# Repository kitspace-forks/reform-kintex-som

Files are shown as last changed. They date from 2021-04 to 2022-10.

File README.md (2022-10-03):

# MNT Reform Kintex-7 SoM (MNT RKX7)

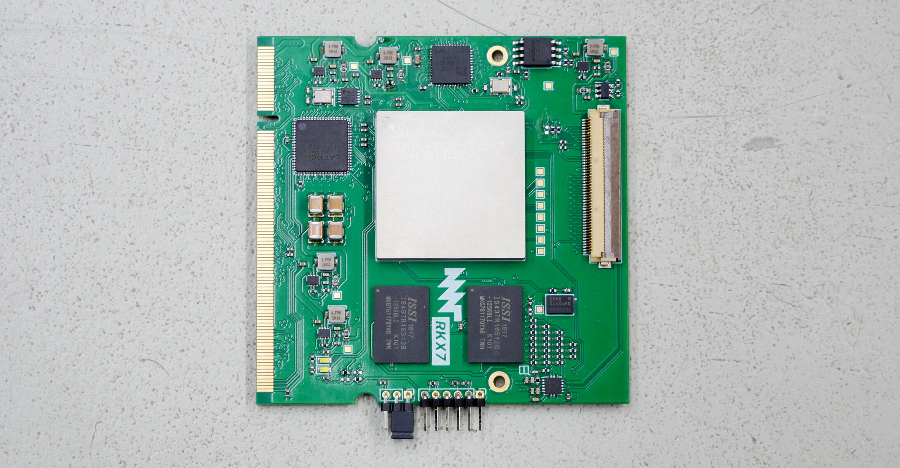
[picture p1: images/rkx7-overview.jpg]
MNT Reform Kintex-7 SoM (MNT RKX7) D-2


This is the open hardware system-on-module featuring the Xilinx/AMD Kintex-7 FPGA (XC7K160T or XC7K325T) and 2GB DDR3 RAM. It can be used as an alternative to the main processor module in the [MNT Reform open hardware laptop](https://www.crowdsupply.com/mnt/reform) or in any other custom device. The idea is to test synthesized open cores such as [CORE-V CVA6](https://github.com/openhwgroup/cva6) (RISC-V), [LiteX](https://github.com/enjoy-digital/litex) (multi-architecture), [LibreSOC](https://libre-soc.org/) (OpenPOWER) in a real laptop. True emulation of vintage computer architectures in a laptop form factor is possible as well.

The module was designed by Lukas F. Hartmann (mntmn) of [MNT Research GmbH](https://mntre.com).

## Status

In September 2022 we assembled and brought up the second revision of the module (D-2) which fixes some problems found in the first revision. We were able to run a full RISC-V Linux desktop on the new module, integrated in the MNT Reform laptop shell. We are using the XC7K325T-FFG676 FPGA. For details, see [the MNT Reform Kintex-7 SoM Showcase](https://mntre.com/media/reform_md/2022-09-29-rkx7-showcase.html).

Changes from D-1:

- The power sequencing IC was missing pullups on the outputs.
- The DDR3 memory routing was completely redone for a less congested layout and avoiding crosstalk. This fixed some address bus errors of the first version.
- The TC358778XBG MIPI encoder was removed. Instead, 24-bit parallel RGB, clocks and extra GPIOs are routed out to a new 50 pin FPC header. This makes the module more flexibly usable.
- We designed a new adapter PCB featuring the Analogix ANX9807 RGB to eDP chip. We are able to successfully drive MNT Reform's eDP Full HD display.
- The TUSB1310ZAY USB3/2 PHY was removed as it is EOL, expensive and there was is no available XHCI host implementation that could drive it. Instead, USB1/2 pads are now driven directly by the FPGA. This works well with the SpinalHDL OHCI host controller which is supported by LiteX.
- 8 FPGA additional pads were broken out to an array of square test points.
- The JTAG header pitch was increased to 2mm for easier access.

The design was created using [KiCAD, a free and open source EDA program](https://www.kicad.org/).

## Specs

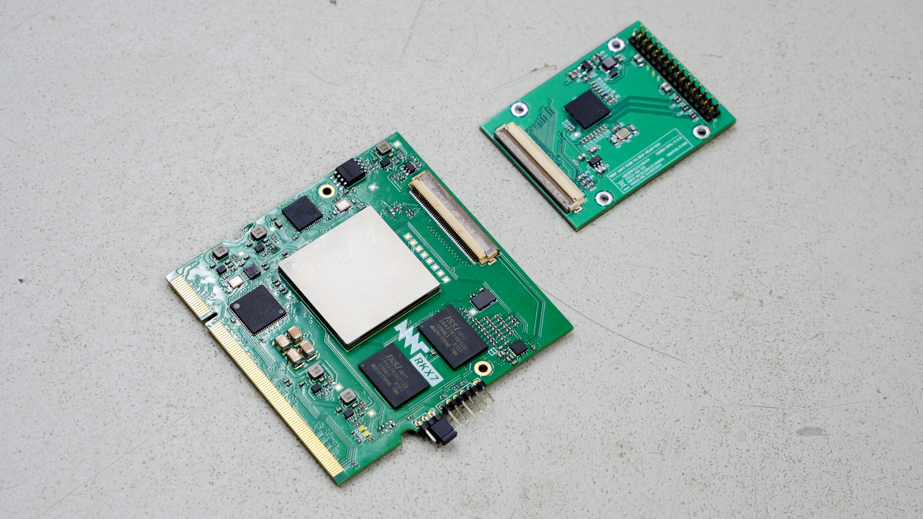
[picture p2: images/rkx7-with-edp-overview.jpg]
MNT Reform Kintex-7 SoM (MNT RKX7) D-2 with eDP module


- FPGA: [Xilinx Kintex-7](https://www.xilinx.com/products/silicon-devices/fpga/kintex-7.html) XC7K160T-FFG676 or pin-compatible family members. We are using XC7K325T-FFG676 in our tests.
- Memory: 2GB DDR3 (2x Micron IS43TR16512B-125KBLI in 32-bit topology)
- 100 MHz main clock oscillator
- HDMI 1.4 (Full HD) implemented via Sii9022 encoder
- 1 GBit Ethernet via KSZ9031RNX PHY
- 2x PCIe lanes connected to GTX transceivers
- 1x USB3 connected to GTX transceiver
- 3x UART, 2x I2C, 1x SAI, 1x PWM backlight ports connected to FPGA fabric
- 128 MBit configuration flash (Winbond W25Q128JVSIM)
- JTAG header
- 6 synchronous buck converters powered by single 5V input
- Size: 68x67.5mm, 200 pin SO-DIMM card edge (mates with TE 1717254-1 or TE 1473005-1)
- Schematics: [PDF](reform-kintex-schematics.pdf)

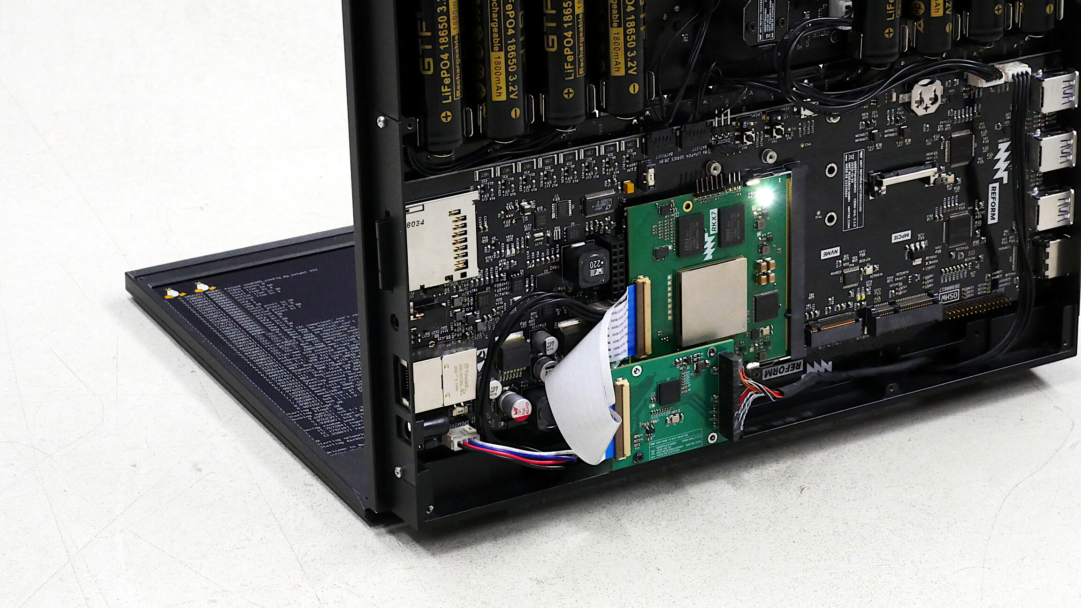
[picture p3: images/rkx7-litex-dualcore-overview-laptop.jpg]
MNT Reform Kintex-7 SoM (MNT RKX7) integrated in MNT Reform laptop


## Copyright

All hardware design work in this repository is © 2021-2022 [MNT Research GmbH](https://mntre.com), Berlin, Germany.

## License

All hardware sources are licensed under the [CERN Open Hardware Licence Version 2 - Strongly Reciprocal](https://ohwr.org/project/cernohl/wikis/uploads/002d0b7d5066e6b3829168730237bddb/cern_ohl_s_v2.txt).

## Funding

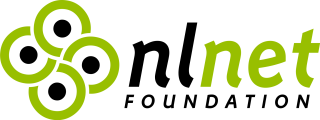
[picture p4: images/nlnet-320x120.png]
NLNet logo


This project [is made possible through funding by NLNet](https://nlnet.nl/project/MNT-Reform/). Thanks!

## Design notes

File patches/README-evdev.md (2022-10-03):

# Evdev Caveat

When demoing Xorg on RKX7 with Linux-on-LiteX-VexRiscV, I encountered the problem that Xorg did not react to any keyboard or mouse input events sent be evdev/libinput. This was due to a disagreement of the timestamps in `struct input_event` in the Linux kernel vs the UAPI used by buildroot: the kernel was producing 32 bit sec/usec values while the userland was expecting 64 bit. I'm not sure how this could happen because buildroot builds both the kernel and the userland.

In any case, my workaround was to patch `struct input_event` in the kernel, in `include/uapi/input.h`:

```c
struct input_event {
	int64_t __sec;
	int64_t __usec;
#define input_event_sec  __sec
#define input_event_usec __usec
	__u16 type;
	__u16 code;
	__s32 value;
};
```

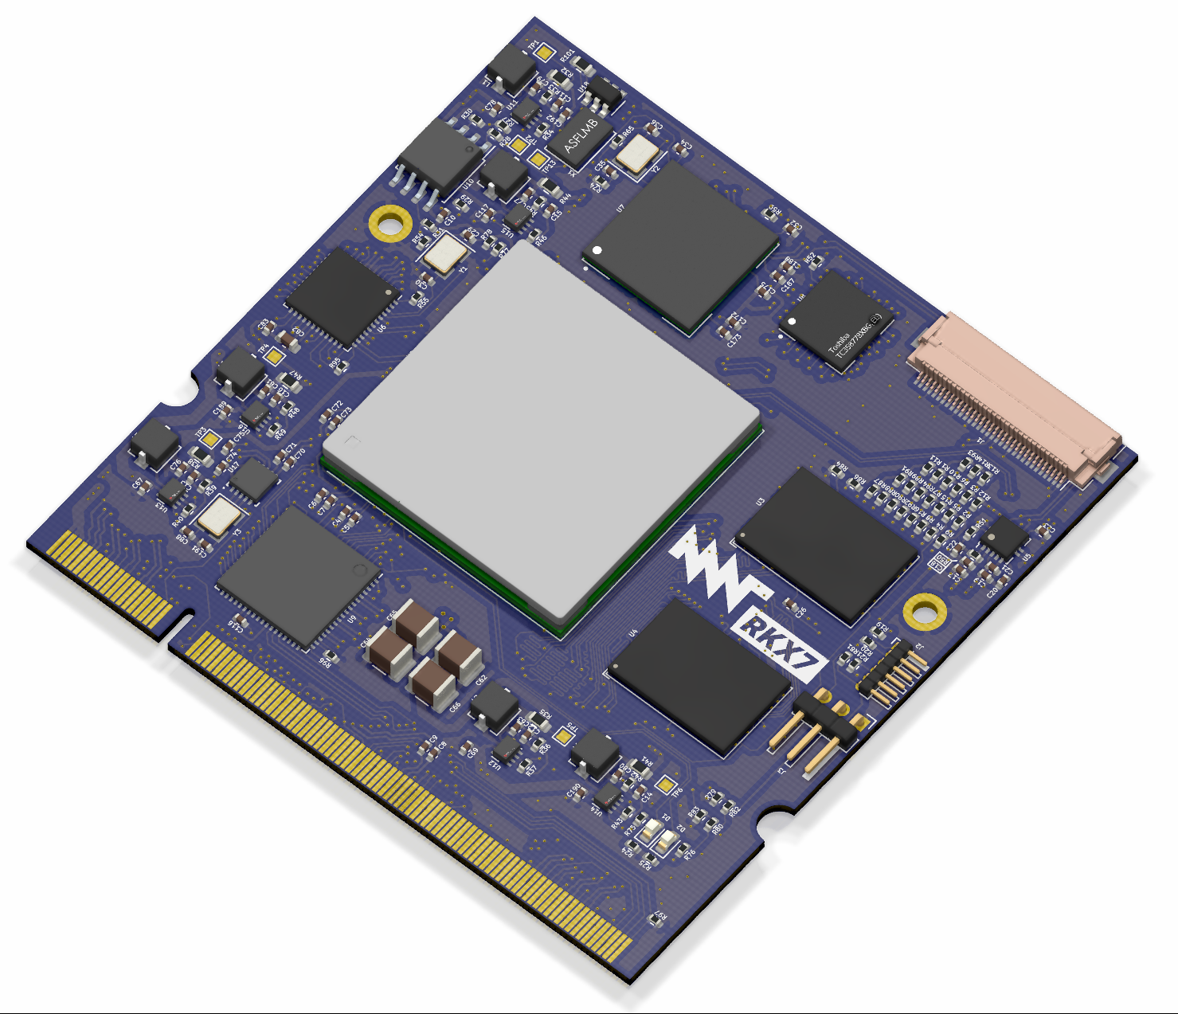
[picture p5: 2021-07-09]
images/mnt-rkx7-3d.png

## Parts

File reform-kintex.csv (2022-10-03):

Source: | /home/mntmn/code/reform-kintex/reform-kintex-pcb/reform-kintex.kicad_sch
Date: | 2022-09-13T12:17:49 CEST
Tool: | Eeschema 6.0.7+dfsg-1+b1
Generator: | /usr/share/kicad/plugins/bom_csv_grouped_by_value_with_fp.py
Component Count: | 297
Ref | Qnty | Value | Cmp name | Footprint | Description | Vendor
C1, C2, C3, C4, C5, C6, C7, C8, C9, C10, C15, C23, C28, C31, C32, C70, C71, C72, C73, C74, C83, C84, C85, C86, C87, C90, C91, C92, C95, C96, C99, C100, C102, C110, C111, C112, C113, C114, C115, C116, C118, C119, C120, C130, C131, C132, C133, C134, C135, C136, C137, C138, C139, C140, C141, C142, C143, C144, C145, C146, C147, C148, C149, C150, C151, C152, C153, C154, C155, C156, C157, C158, C159, C160, C161, C162, C163, C164, C165, C192, | 80 | 0.1uF | C_Small | Capacitor_SMD:C_0402_1005Metric | Unpolarized capacitor, small symbol
C11, C12, C13, C14, C16, | 5 | 120pF | C_Small | Capacitor_SMD:C_0402_1005Metric | Unpolarized capacitor, small symbol
C17, C18, C19, C20, C21, C63, C76, C79, C80, C81, C101, | 11 | 10uF | C_Small | Capacitor_SMD:C_0402_1005Metric | Unpolarized capacitor, small symbol
C22, | 1 | 1nF | C_Small | Capacitor_SMD:C_0402_1005Metric | Unpolarized capacitor, small symbol
C24, C25, C26, C27, C103, | 5 | 10nF | C_Small | Capacitor_SMD:C_0402_1005Metric | Unpolarized capacitor, small symbol
C29, C30, C88, C191, | 4 | 22pF | C_Small | Capacitor_SMD:C_0402_1005Metric | Unpolarized capacitor, small symbol
C37, C38, C39, C40, C41, C42, C60, C61, C68, | 9 | 100uF | C_Small | Capacitor_SMD:C_1206_3216Metric | Unpolarized capacitor, small symbol
C43, C44, C45, C46, C47, C48, C49, C50, C51, C56, C57, C58, C59, C67, C69, C75, C78, C104, C105, C106, C107, C108, C109, C189, C190, | 25 | 4.7uF | C_Small | Capacitor_SMD:C_0402_1005Metric | Unpolarized capacitor, small symbol
C52, C53, C54, C55, | 4 | 47uF | C_Small | Capacitor_SMD:C_1206_3216Metric | Unpolarized capacitor, small symbol
C62, C64, C65, C66, | 4 | 220uF | C_Small | Capacitor_SMD:C_1210_3225Metric | Unpolarized capacitor, small symbol
C82, C89, C93, C94, C97, C98, | 6 | 10uF | C_Small | Capacitor_SMD:C_0603_1608Metric | Unpolarized capacitor, small symbol
D1, D2, | 2 | LED_Small | LED_Small | LED_SMD:LED_0603_1608Metric | Light emitting diode, small symbol
FB1, FB2, FB3, | 3 | Ferrite_Bead_Small | FerriteBead_Small | Inductor_SMD:L_0603_1608Metric | Ferrite bead, small symbol
GFX1, | 1 | MountingHole | MountingHole | footprints:mnt-rkx7 | Mounting Hole without connection
GFX2, | 1 | MountingHole | MountingHole | footprints:mnt-rkx7-badge-d02 | Mounting Hole without connection
H1, H2, | 2 | MountingHole_Pad | MountingHole_Pad | MountingHole:MountingHole_2.2mm_M2_DIN965_Pad | Mounting Hole with connection
J1, | 1 | Conn_01x50 | Conn_01x50 | Connector_FFC-FPC:Hirose_FH12-50S-0.5SH_1x50-1MP_P0.50mm_Horizontal | Generic connector, single row, 01x50, script generated (kicad-library-utils/symbol-generators/connector/)
J2, | 1 | JTAG_01x06 | Conn_01x06 | Connector_PinHeader_2.00mm:PinHeader_1x06_P2.00mm_Vertical | Generic connector, single row, 01x06, script generated (kicad-library-utils/schlib/autogen/connector/)
J3, | 1 | Conn_01x03_Male | Conn_01x03_Male | Connector_PinHeader_2.00mm:PinHeader_1x03_P2.00mm_Vertical | Generic connector, single row, 01x03, script generated (kicad-library-utils/schlib/autogen/connector/)
L1, L2, L3, L4, L6, | 5 | IHLP1212AEERR47M11 | L_Small | Inductor_SMD:L_Vishay_IHLP-1212 | Inductor, small symbol
R1, R2, R3, R4, R5, R6, R7, R8, R9, R10, R11, R12, R13, R14, R15, R16, R87, R88, R89, R90, R91, R92, R93, R94, | 24 | 40.2 | R_Small | Resistor_SMD:R_0402_1005Metric | Resistor, small symbol
R17, R18, R86, R99, R100, | 5 | 80.6 | R_Small | Resistor_SMD:R_0402_1005Metric | Resistor, small symbol
R19, R20, R21, R77, R98, | 5 | 100 | R_Small | Resistor_SMD:R_0402_1005Metric | Resistor, small symbol
R22, R23, R26, R30, R31, R71, R75, R95, R102, R103, R104, R105, R106, R107, R108, R109, | 16 | 4.7k | R_Small | Resistor_SMD:R_0402_1005Metric | Resistor, small symbol
R24, R25, | 2 | 200 | R_Small | Resistor_SMD:R_0402_1005Metric | Resistor, small symbol
R27, | 1 | 2.2k | R_Small | Resistor_SMD:R_0402_1005Metric | Resistor, small symbol
R28, R29, R79, R80, R81, R110, | 6 | 0 | R_Small | Resistor_SMD:R_0402_1005Metric | Resistor, small symbol
R32, R35, R38, R41, R47, R101, | 6 | 0 | R_Small | Resistor_SMD:R_0603_1608Metric | Resistor, small symbol
R33, | 1 | 453k | R_Small | Resistor_SMD:R_0402_1005Metric | Resistor, small symbol
R34, R36, R40, R43, R48, R49, R52, R53, | 8 | 100k 1% | R_Small | Resistor_SMD:R_0402_1005Metric | Resistor, small symbol
R37, R42, | 2 | 150k | R_Small | Resistor_SMD:R_0402_1005Metric | Resistor, small symbol
R39, | 1 | 200k | R_Small | Resistor_SMD:R_0402_1005Metric | Resistor, small symbol
R44, R45, | 2 | 20 | R_Small | Resistor_SMD:R_0402_1005Metric | Resistor, small symbol
R46, | 1 | 1.5k | R_Small | Resistor_SMD:R_0402_1005Metric | Resistor, small symbol
R50, R51, R97, | 3 | 10k 1% | R_Small | Resistor_SMD:R_0402_1005Metric | Resistor, small symbol
R54, | 1 | 1.8M | R_Small | Resistor_SMD:R_0402_1005Metric | Resistor, small symbol
R55, | 1 | 12.1k | R_Small | Resistor_SMD:R_0402_1005Metric | Resistor, small symbol
R76, | 1 | 330 | R_Small | Resistor_SMD:R_0402_1005Metric | Resistor, small symbol
R78, R82, R83, | 3 | DNP | R_Small | Resistor_SMD:R_0402_1005Metric | Resistor, small symbol
R84, R85, | 2 | 240 1% | R_Small | Resistor_SMD:R_0402_1005Metric | Resistor, small symbol
R96, | 1 | 5.1k | R_Small | Resistor_SMD:R_0402_1005Metric | Resistor, small symbol
TP1, TP2, TP3, TP4, TP5, TP6, TP7, TP8, TP9, TP10, TP11, TP12, TP13, TP14, TP15, TP16, | 16 | TestPoint | TestPoint | TestPoint:TestPoint_Pad_1.0x1.0mm | test point
U1, | 1 | MNT Reform 2.0 SoM Socket | reform2-som-connector-reform2-som | footprints:ddr2-sodimm200
U2, | 1 | XC7K160T-FFG676 | XC7K160T-FFG676 | Package_BGA:Xilinx_FFG676 | Kintex 7 T 160 XC7K160T-FFG676
U3, U4, | 2 | IS43TR16512B-125KBLI | gkl_mem_MT41K64M16TW-107_J-TR-OrangeCrab-cache | Package_BGA:BGA-96_9.0x13.0mm_Layout2x3x16_P0.8mm
U5, | 1 | TPS51200DRC | TPS51200DRC | Package_SON:VSON-10-1EP_3x3mm_P0.5mm_EP1.65x2.4mm | Sink and Source DDR Termination Regulator, VSON-10
U6, | 1 | KSZ9031RNX | KSZ9031RNXCA | Package_DFN_QFN:QFN-48-1EP_7x7mm_P0.5mm_EP5.15x5.15mm | 10/100/1000Mbps Ethernet Transciever with RGMII Interface, QFN-48
U9, | 1 | SiI9022A | SiI9022A-zz9000 | Package_DFN_QFN:QFN-72-1EP_10x10mm_P0.5mm_EP6x6mm
U10, | 1 | W25Q128JVS | W25Q128JVS | Package_SO:SOIC-8_5.23x5.23mm_P1.27mm | 128Mb Serial Flash Memory, Standard/Dual/Quad SPI, SOIC-8
U11, U12, U13, U14, U16, | 5 | TPS62823DLC | TPS62823DLC | Package_DFN_QFN:Texas_VSON-HR-8_1.5x2mm_P0.5mm | 3A Step-Down Converter with DCS-Control, adjustable output, 2.4-5.5V input voltage, QFN-8
U17, | 1 | Si52112-B5-GM2 | Si52112-B5 | footprints:Silicon_Labs-Si52112-B5-GM2-Level_B
U18, | 1 | LM3880 | LM3880 | Package_TO_SOT_SMD:SOT-23-6 | Simple Power Sequencer, SOT-23-6
X1, | 1 | ASFLMB-100.000MHZ-XY-T | ASE-xxxMHz | footprints:OSCDFN500X320X90-4N | 3.3V CMOS SMD Crystal Clock Oscillator, Abracon
Y1, Y3, | 2 | ABM8G-25.000MHZ-18-D2Y-T | Crystal_GND24_Small | Crystal:Crystal_SMD_3225-4Pin_3.2x2.5mm | Four pin crystal, GND on pins 2 and 4, small symbol

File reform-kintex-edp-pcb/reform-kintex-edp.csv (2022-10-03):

Source: | /home/mntmn/code/reform-kintex/reform-kintex-edp-pcb/reform-kintex-edp.kicad_sch
Date: | 2022-09-16T13:49:18 CEST
Tool: | Eeschema 6.0.7+dfsg-1+b1
Generator: | /usr/share/kicad/plugins/bom_csv_grouped_by_value_with_fp.py
Component Count: | 54
Ref | Qnty | Value | Cmp name | Footprint | Description | Vendor
C1, C17, | 2 | 10uF | C_Small | Capacitor_SMD:C_0603_1608Metric | Unpolarized capacitor, small symbol
C2, C10, | 2 | 4.7uF | C_Small | Capacitor_SMD:C_0603_1608Metric | Unpolarized capacitor, small symbol
C3, C6, | 2 | 18pF | C_Small | Capacitor_SMD:C_0603_1608Metric | Unpolarized capacitor, small symbol
C4, C5, C8, C9, C11, C12, C13, C14, C15, C16, C18, C19, C20, C21, C22, C25, C26, C27, C28, C29, C30, | 21 | 0.1uF | C_Small | Capacitor_SMD:C_0402_1005Metric | Unpolarized capacitor, small symbol
C7, | 1 | 10nF | C_Small | Capacitor_SMD:C_0603_1608Metric | Unpolarized capacitor, small symbol
C23, C24, | 2 | 47uF | C_Small | Capacitor_SMD:C_0805_2012Metric | Unpolarized capacitor, small symbol
D1, | 1 | PMEG1020EA,115 | D_Schottky_Small_Filled | Diode_SMD:D_SOD-323 | Schottky diode, small symbol, filled shape
H1, H2, H3, H4, | 4 | MountingHole_Pad | MountingHole_Pad | MountingHole:MountingHole_2.2mm_M2_DIN965_Pad | Mounting Hole with connection
H5, | 1 | Badge | MountingHole | footprints:mnt-rgb-edp-badge | Mounting Hole without connection
J1, | 1 | Conn_01x50 | Conn_01x50 | Connector_FFC-FPC:Hirose_FH12-50S-0.5SH_1x50-1MP_P0.50mm_Horizontal | Generic connector, single row, 01x50, script generated (kicad-library-utils/symbol-generators/connector/)
J2, | 1 | ~ | Conn_02x15_Odd_Even | Connector_PinHeader_2.00mm:PinHeader_2x15_P2.00mm_Vertical | Generic connector, double row, 02x15, odd/even pin numbering scheme (row 1 odd numbers, row 2 even numbers), script generated (kicad-library-utils/schlib/autogen/connector/)
L1, | 1 | 3.3uH | L_Small | Inductor_SMD:L_1210_3225Metric | Inductor, small symbol
R1, | 1 | 12k 1% | R_Small | Resistor_SMD:R_0603_1608Metric | Resistor, small symbol
R2, R4, R5, R9, R10, | 5 | 0 | R_Small | Resistor_SMD:R_0603_1608Metric | Resistor, small symbol
R3, | 1 | 100k | R_Small | Resistor_SMD:R_0603_1608Metric | Resistor, small symbol
R6, | 1 | 1M | R_Small | Resistor_SMD:R_0603_1608Metric | Resistor, small symbol
R7, R8, | 2 | 15k 1% | R_Small | Resistor_SMD:R_0603_1608Metric | Resistor, small symbol
TP1, | 1 | TestPoint | TestPoint | TestPoint:TestPoint_Pad_D1.0mm | test point
U1, | 1 | LP2985A-25DBVT | LP2985-2.5 | Package_TO_SOT_SMD:SOT-23-5 | 150mA 16V Low-noise Low-dropout Regulator With Shutdown, 2.5V output voltage, SOT-23-5
U2, | 1 | LM2830XQMFE/NOPB | LM2830XQMFE | Package_TO_SOT_SMD:SOT-23-5 | Miniature Step-Down DC-DC Converter for Ultralow Voltage Circuits, 2.5V < Vin < 5.5V, adjustable output voltage, SOT-23-5
U3, | 1 | ANX9807 | ANX9807 | footprints:BGA-ANX-81
Y1, | 1 | 27MHz | Crystal_GND24_Small | Crystal:Crystal_SMD_3225-4Pin_3.2x2.5mm | Four pin crystal, GND on pins 2 and 4, small symbol

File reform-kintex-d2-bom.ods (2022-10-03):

Qty | Reference(s) | Value | DNP | Manufacturer | Manufacturer_No
80 | C1, C2, C3, C4, C5, C6, C7, C8, C9, C10, C15, C23, C28, C31, C32, C70, C71, C72, C73, C74, C83, C84, C85, C86, C87, C90, C91, C92, C95, C96, C99, C100, C102, C110, C111, C112, C113, C114, C115, C116, C118, C119, C120, C130, C131, C132, C133, C134, C135, C136, C137, C138, C139, C140, C141, C142, C143, C144, C145, C146, C147, C148, C149, C150, C151, C152, C153, C154, C155, C156, C157, C158, C159, C160, C161, C162, C163, C164, C165, C192 | 0.1uF |  | Taiyo Yuden | EMF105B7104KVHF
5 | C11, C12, C13, C14, C16 | 120pF |  | Taiyo Yuden | UMK105CG121JV8F
11 | C17, C18, C19, C20, C21, C63, C76, C79, C80, C81, C101 | 10uF |  | Murata | GRM155R60J106ME15D
1 | C22 | 1nF |  | Murata | GRT1555C1H102FA02D
5 | C24, C25, C26, C27, C103 | 10nF |  | Kemet | C0402C103K5RAC7411
4 | C29, C30, C88, C191 | 22pF |  | Kemet | C0402C220J8HACTU
9 | C37, C38, C39, C40, C41, C42, C60, C61, C68 | 100uF |  | Murata | GRM31CR61A107ME05L
25 | C43, C44, C45, C46, C47, C48, C49, C50, C51, C56, C57, C58, C59, C67, C69, C75, C78, C104, C105, C106, C107, C108, C109, C189, C190 | 4.7uF |  | Murata | GRJ155R61A475ME11J
4 | C52, C53, C54, C55 | 47uF |  | Taiyo Yuden | JMK316AC7476ML-T
4 | C62, C64, C65, C66 | 220uF |  | Murata | GRM32ER60J227ME05L
6 | C82, C89, C93, C94, C97, C98 | 10uF |  | Generic | 0603 10V+
2 | D1, D2 | LED_Small |  | Generic | WLED 0603
3 | FB1, FB2, FB3 | Ferrite_Bead_Small |  | Murata | 100ohms @ 100MHz 0603
1 | J1 | Conn_01x50 |  | Hirose | FH12-50S-0.5SH
1 | J2 | JTAG_01x06 |  | Sullins | SMH100-LPSE
1 | J3 | Conn_01x03_Male |  | Harwin | M22-2530346
5 | L1, L2, L3, L4, L6 | IHLP1212AEERR47M11 |  | Vishay Dale | IHLP1212AEERR47M11
24 | R1, R2, R3, R4, R5, R6, R7, R8, R9, R10, R11, R12, R13, R14, R15, R16, R87, R88, R89, R90, R91, R92, R93, R94 | 40.2 |  | Yageo | RT0402FRE0740R2L
5 | R17, R18, R86, R99, R100 | 80.6 |  | Yageo | AF0402FR-0780R6L
5 | R19, R20, R21, R77, R98 | 100 |  | Yageo | RT0402FRE07100RL
16 | R22, R23, R26, R30, R31, R71, R75, R95, R102, R103, R104, R105, R106, R107, R108, R109 | 4.7k |  | Bourns | CR0402-FX-4701GLF
2 | R24, R25 | 200 |  | Yageo | AF0402JR-07200RL
1 | R27 | 2.2k |  | Vishay Dale | CRCW04022K20JNED
6 | R28, R29, R79, R80, R81, R110 | 0 |  | Yageo | AC0402FR-070RL
6 | R32, R35, R38, R41, R47, R101 | 0 |  | Yageo | AC0402FR-070RL
1 | R33 | 453k |  | Yageo | AC0402FR-07453KL
8 | R34, R36, R40, R43, R48, R49, R52, R53 | 100k 1% |  | Vishay Dale | CRCW0402100KFKEDC
2 | R37, R42 | 150k |  | Yageo | RE0402DRE07150KL
1 | R39 | 200k |  | Yageo | RE0402DRE07200KL
2 | R44, R45 | 20 |  | Yageo | AC0402FR-070RL
1 | R46 | 1.5k |  | Yageo | AC0402FR-070RL
3 | R50, R51, R97 | 10k 1% |  | Yageo | RC0402FR-0710KL
1 | R54 | 1.8M |  | Yageo | RC0402FR-071M8L
1 | R55 | 12.1k |  | Yageo | RT0402FRE0712K1L
1 | R76 | 330 |  | Yageo | RC0402JR-07330RL
3 | R78, R82, R83 | DNP | DNP | DNP | DNP
2 | R84, R85 | 240 1% |  | Yageo | RC0402FR-07240RL
1 | R96 | 5.1k |  | Yageo | RC0402FR-075K1L
1 | U1 | MNT Reform 2.0 SoM Socket |  | TE | 1717254-1
1 | U2 | XC7K160T-FFG676 |  | Xilinx | XC7K160T-FFG676
2 | U3, U4 | IS43TR16512B-125KBLI |  | Micron | IS43TR16512B-125KBLI
1 | U5 | TPS51200DRC |  | TI | TPS51200DRC
1 | U6 | KSZ9031RNX |  | Microchip | KSZ9031RNX
1 | U9 | SiI9022A |  | Lattice | SiI9022A
1 | U10 | W25Q128JVS |  | Winbond | W25Q128JVS
5 | U11, U12, U13, U14, U16 | TPS62823DLC |  | TI | TPS62823DLC
1 | U17 | Si52112-B5-GM2 |  | Silicon Labs | Si52112-B5-GM2
1 | U18 | LM3880 |  | TI | LM3880
1 | X1 | ASFLMB-100.000MHZ-XY-T |  | Abracon | ASFLMB-100.000MHZ-XY-T
2 | Y1, Y3 | ABM8G-25.000MHZ-18-D2Y-T |  | Ecliptek | EA2532XA18-25.000M

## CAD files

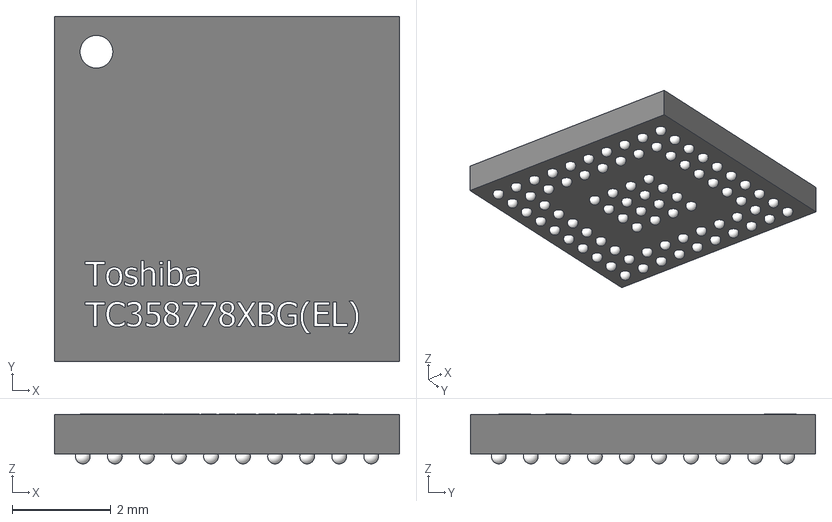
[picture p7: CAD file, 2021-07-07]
3d-models/Toshiba_-_TC358778XBG(EL).step
7.00 x 7.00 x 1.01 mm

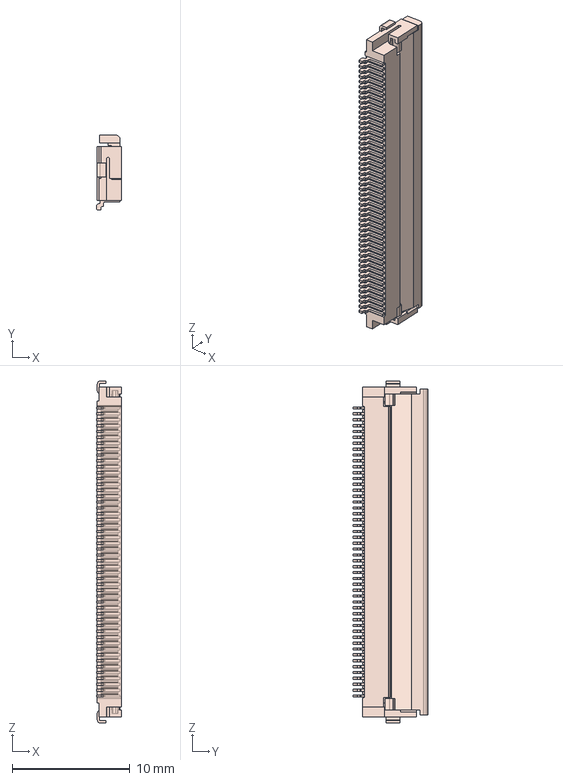
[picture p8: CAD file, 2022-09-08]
reform-kintex-edp-pcb/3d-models/FH12-50S-0.5SH.stp
2.10 x 6.40 x 29.1 mm

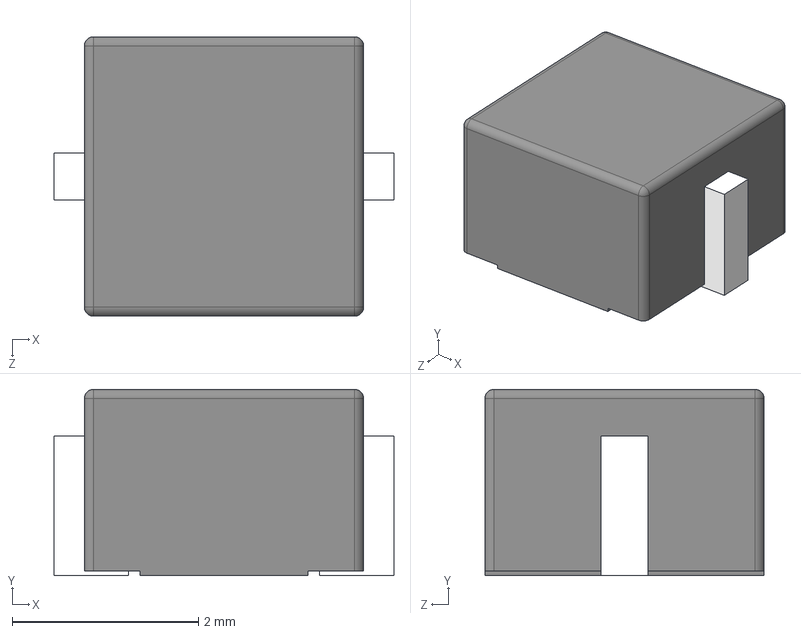
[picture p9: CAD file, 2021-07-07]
3d-models/IHLP1212BZER3R3M11--3DModel-STEP-56544.STEP
3.65 x 2.00 x 3.00 mm

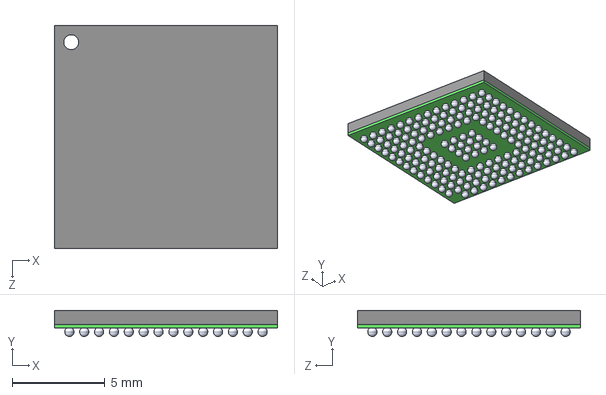
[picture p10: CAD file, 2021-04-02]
footprints/TUSB1310ZAY.step
12.0 x 1.40 x 12.0 mm

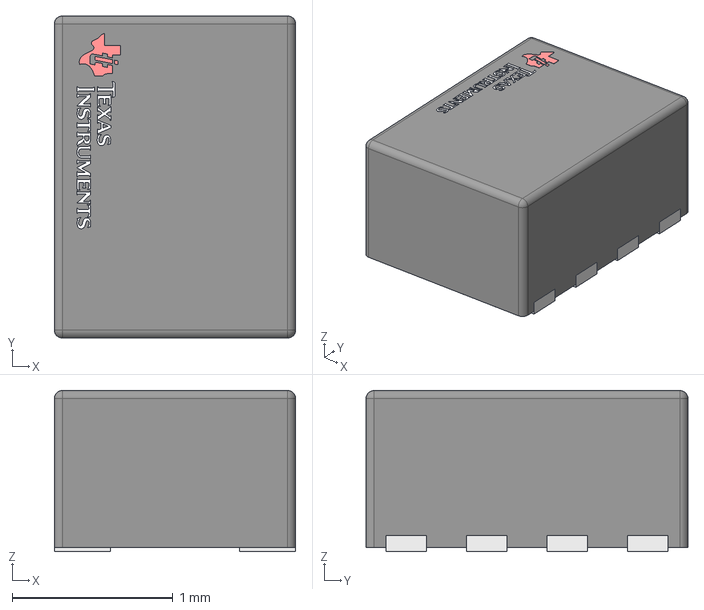
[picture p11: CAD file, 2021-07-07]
3d-models/Texas_Instruments_-_TPS62823DLCR.step
1.50 x 2.00 x 1.00 mm

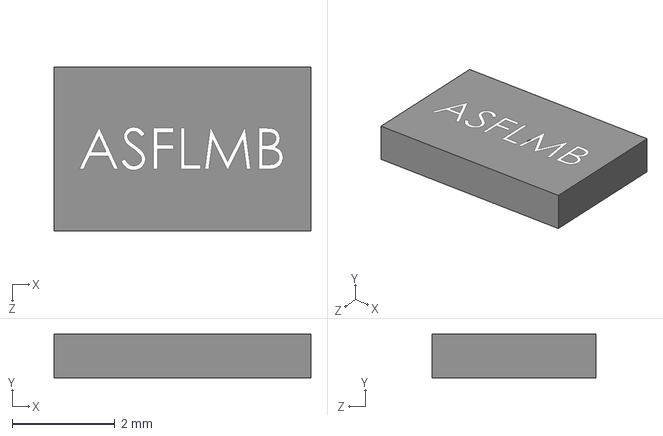
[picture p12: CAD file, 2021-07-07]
3d-models/ASFLMB.STEP
5.00 x 0.851 x 3.20 mm

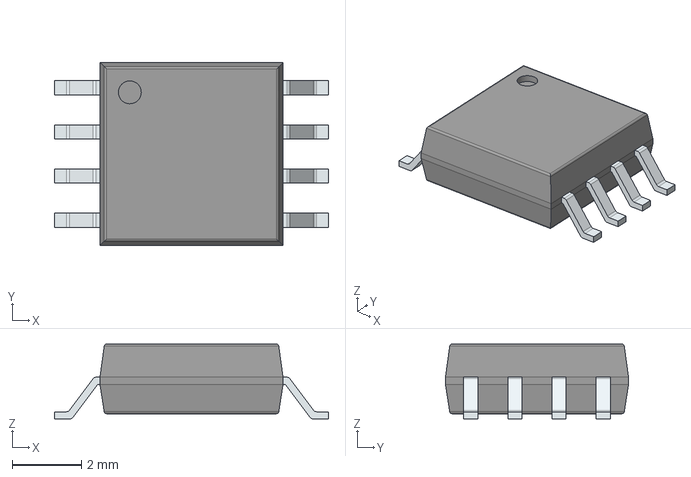
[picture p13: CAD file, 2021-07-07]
3d-models/Winbond_-_W25Q128JVSIM.step
7.90 x 5.28 x 2.16 mm

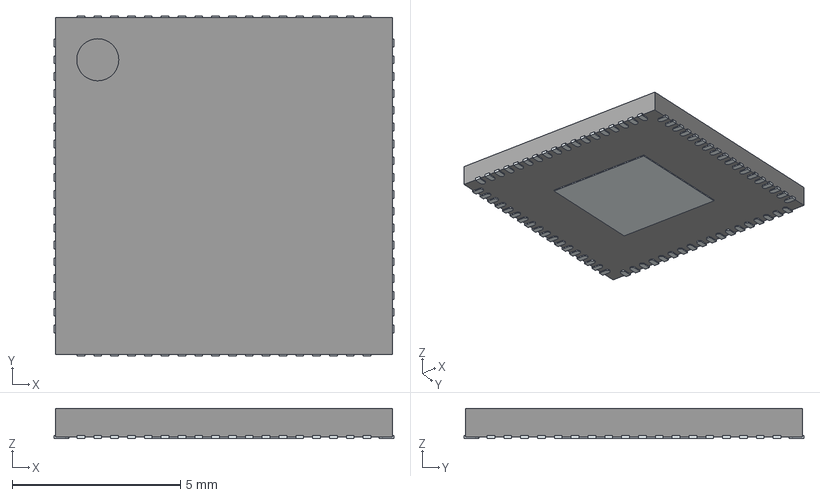
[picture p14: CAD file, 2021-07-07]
3d-models/LIFCL-40-7SG72C.stp
10.1 x 10.1 x 0.9 mm
ThermalPin
PinsArrayLR
PinsArrayTB

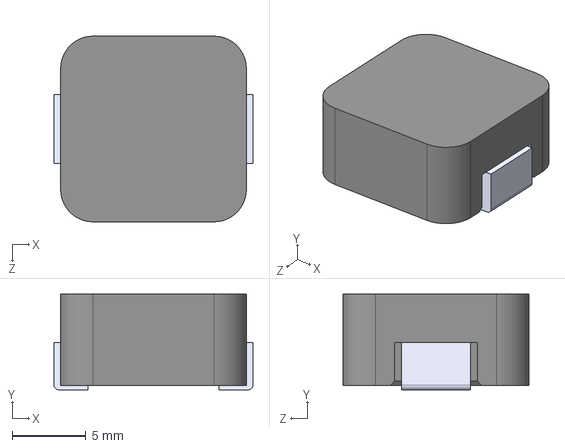
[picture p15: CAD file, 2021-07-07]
3d-models/MGV1207R68M-10.STEP
13.5 x 6.50 x 12.6 mm

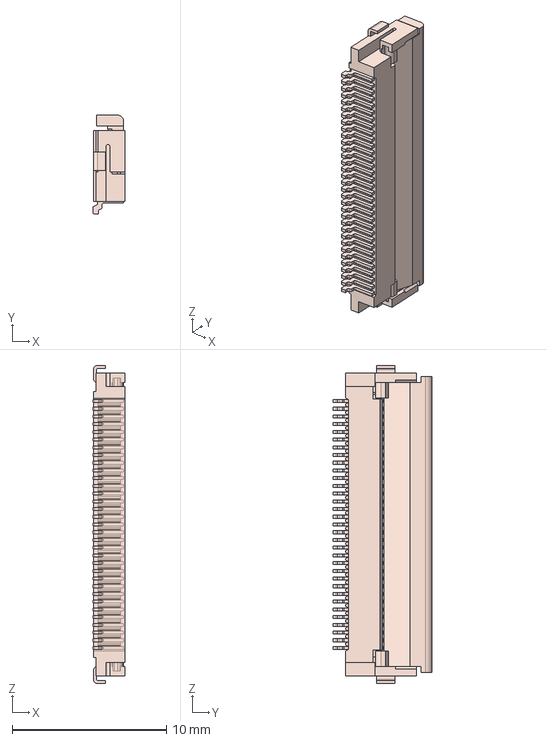
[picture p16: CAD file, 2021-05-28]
3d-models/FH12-33S-0.5SH.stp
2.10 x 6.40 x 20.6 mm

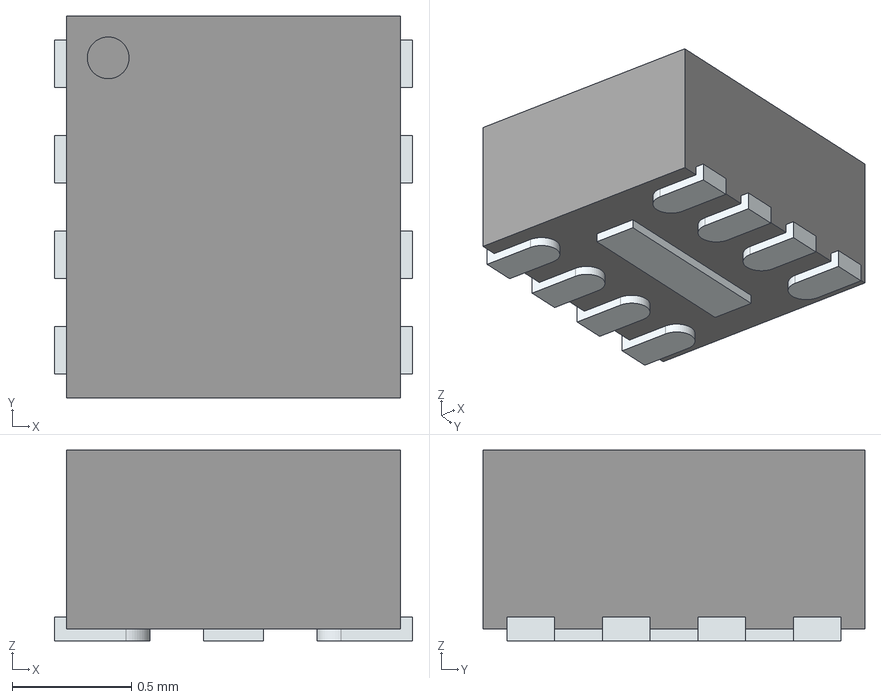
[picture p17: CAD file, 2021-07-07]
3d-models/SI52112-B5-GM3.stp
1.50 x 1.60 x 0.8 mm
ThermalPin
PinsArrayLR

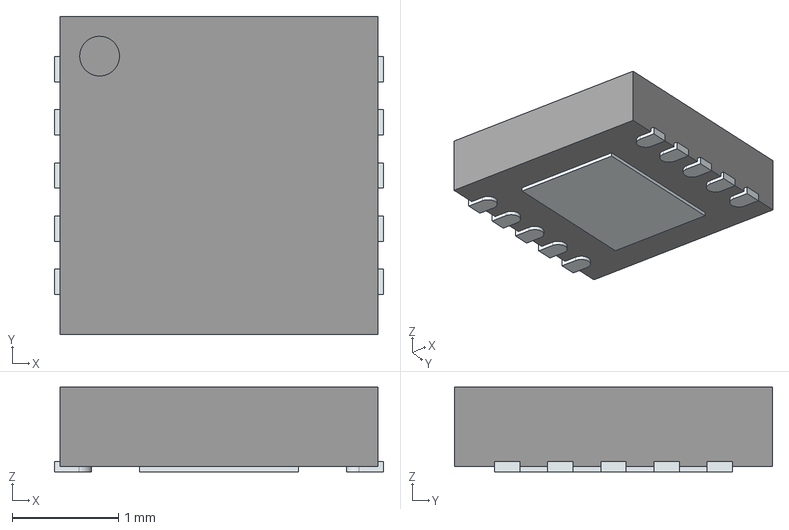
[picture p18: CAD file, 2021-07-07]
3d-models/Si52112-B6-GM2.stp
3.10 x 3.00 x 0.8 mm
ThermalPin
PinsArrayLR

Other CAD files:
footprints/TC358867XBG.step

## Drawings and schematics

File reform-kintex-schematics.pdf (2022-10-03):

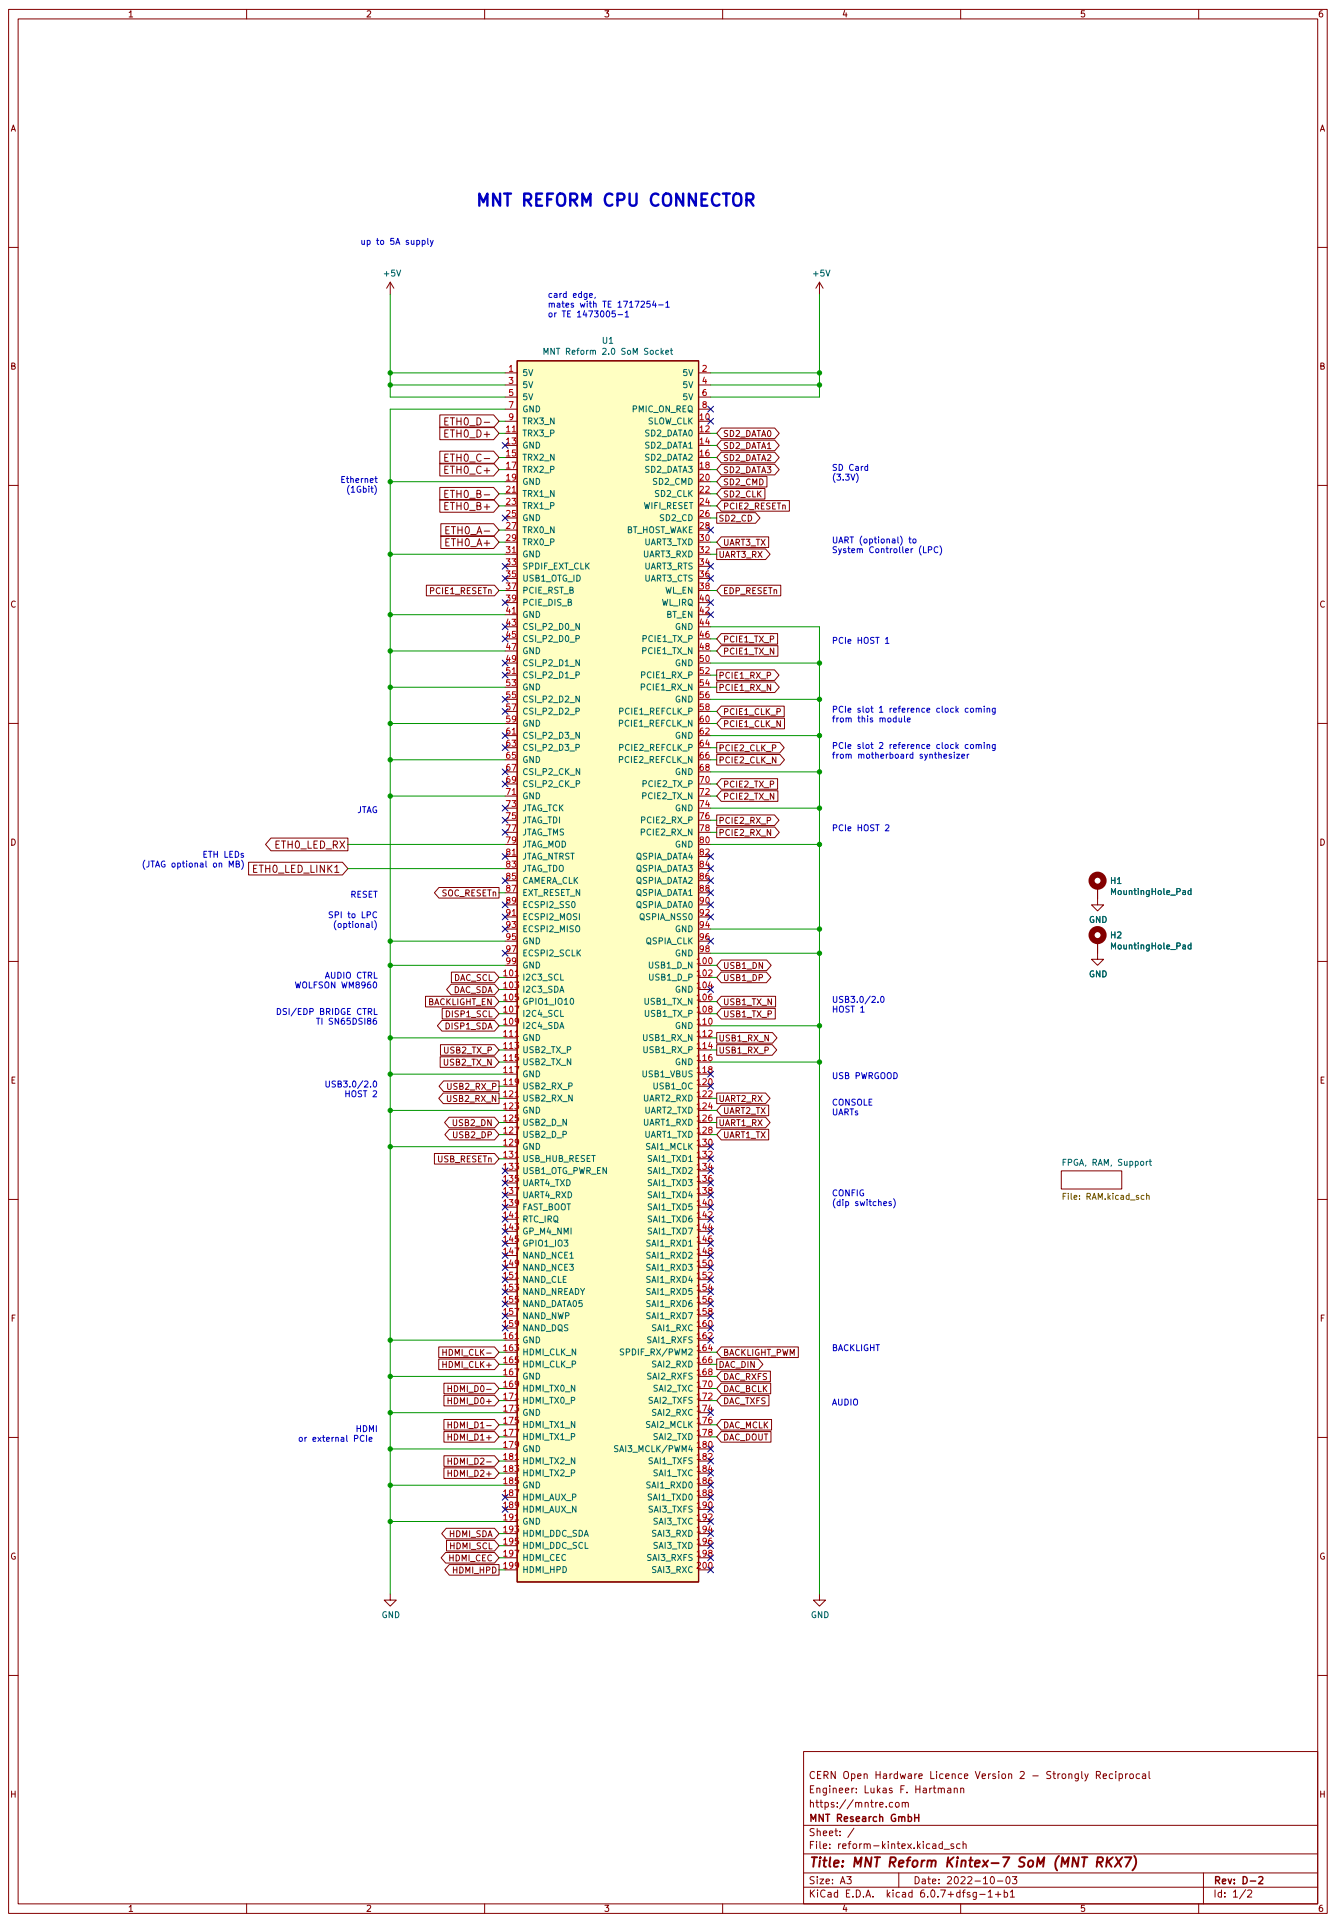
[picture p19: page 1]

MNT REFORM CPU CONNECTOR

PCIe slot 1 reference clock coming
from this module PCIe slot 2 reference clock coming

H2MountingHole_Pad H1MountingHole_Pad
FPGA, RAM, Support File: RAM.kicad_sch GND GND

HDMI or external PCIe

CERN Open Hardware Licence Version 2 - Strongly Reciprocal
Engineer: Lukas F. Hartmann
https://mntre.com
File: reform-kintex.kicad_sch Sheet: / MNT Research GmbH

Id: 1/2 Title: MNT Reform Kintex-7 SoM (MNT RKX7)

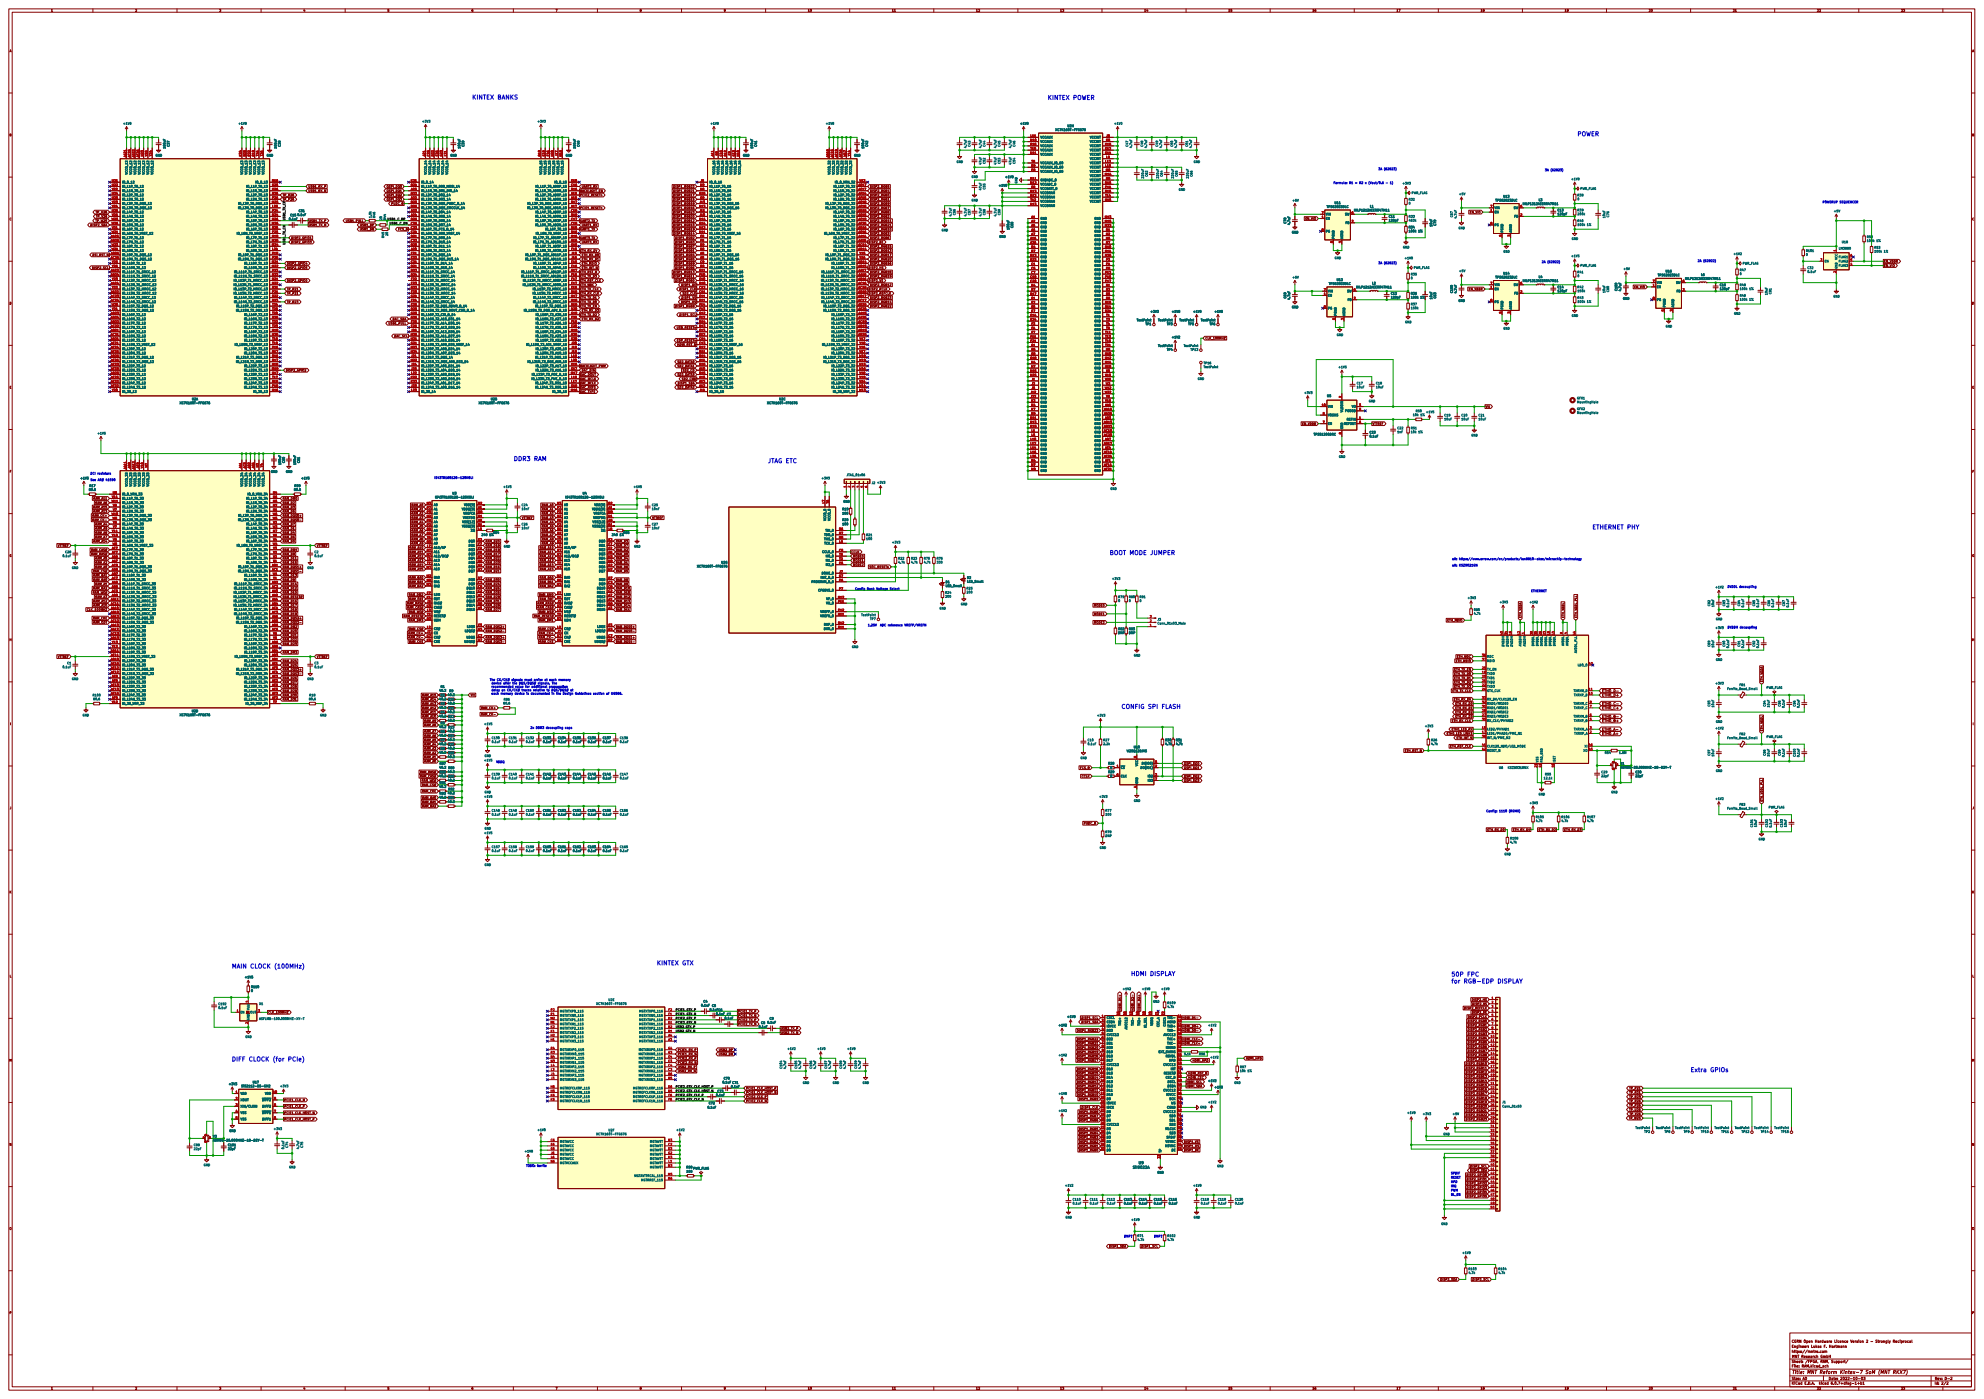
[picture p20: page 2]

alt: https://www.arrow.com/en/products/lan8810-akze/microchip-technology

Config Bank Voltage Select VDDQ

The CK/CK# signals must arrive at each memory
device after the DQS/DQS# signals. The
recommended value for additional propagation
delay on CK/CK# traces relative to DQS/DQS# at
each memory device is documented in the Design Guidelines section of UG586.

DIFF CLOCK (for PCIe)

CERN Open Hardware Licence Version 2 - Strongly Reciprocal
Engineer: Lukas F. Hartmann
https://mntre.com
Sheet: /FPGA, RAM, Support/ MNT Research GmbH

File: RAM.kicad_sch
Id: 2/2 Title: MNT Reform Kintex-7 SoM (MNT RKX7)
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

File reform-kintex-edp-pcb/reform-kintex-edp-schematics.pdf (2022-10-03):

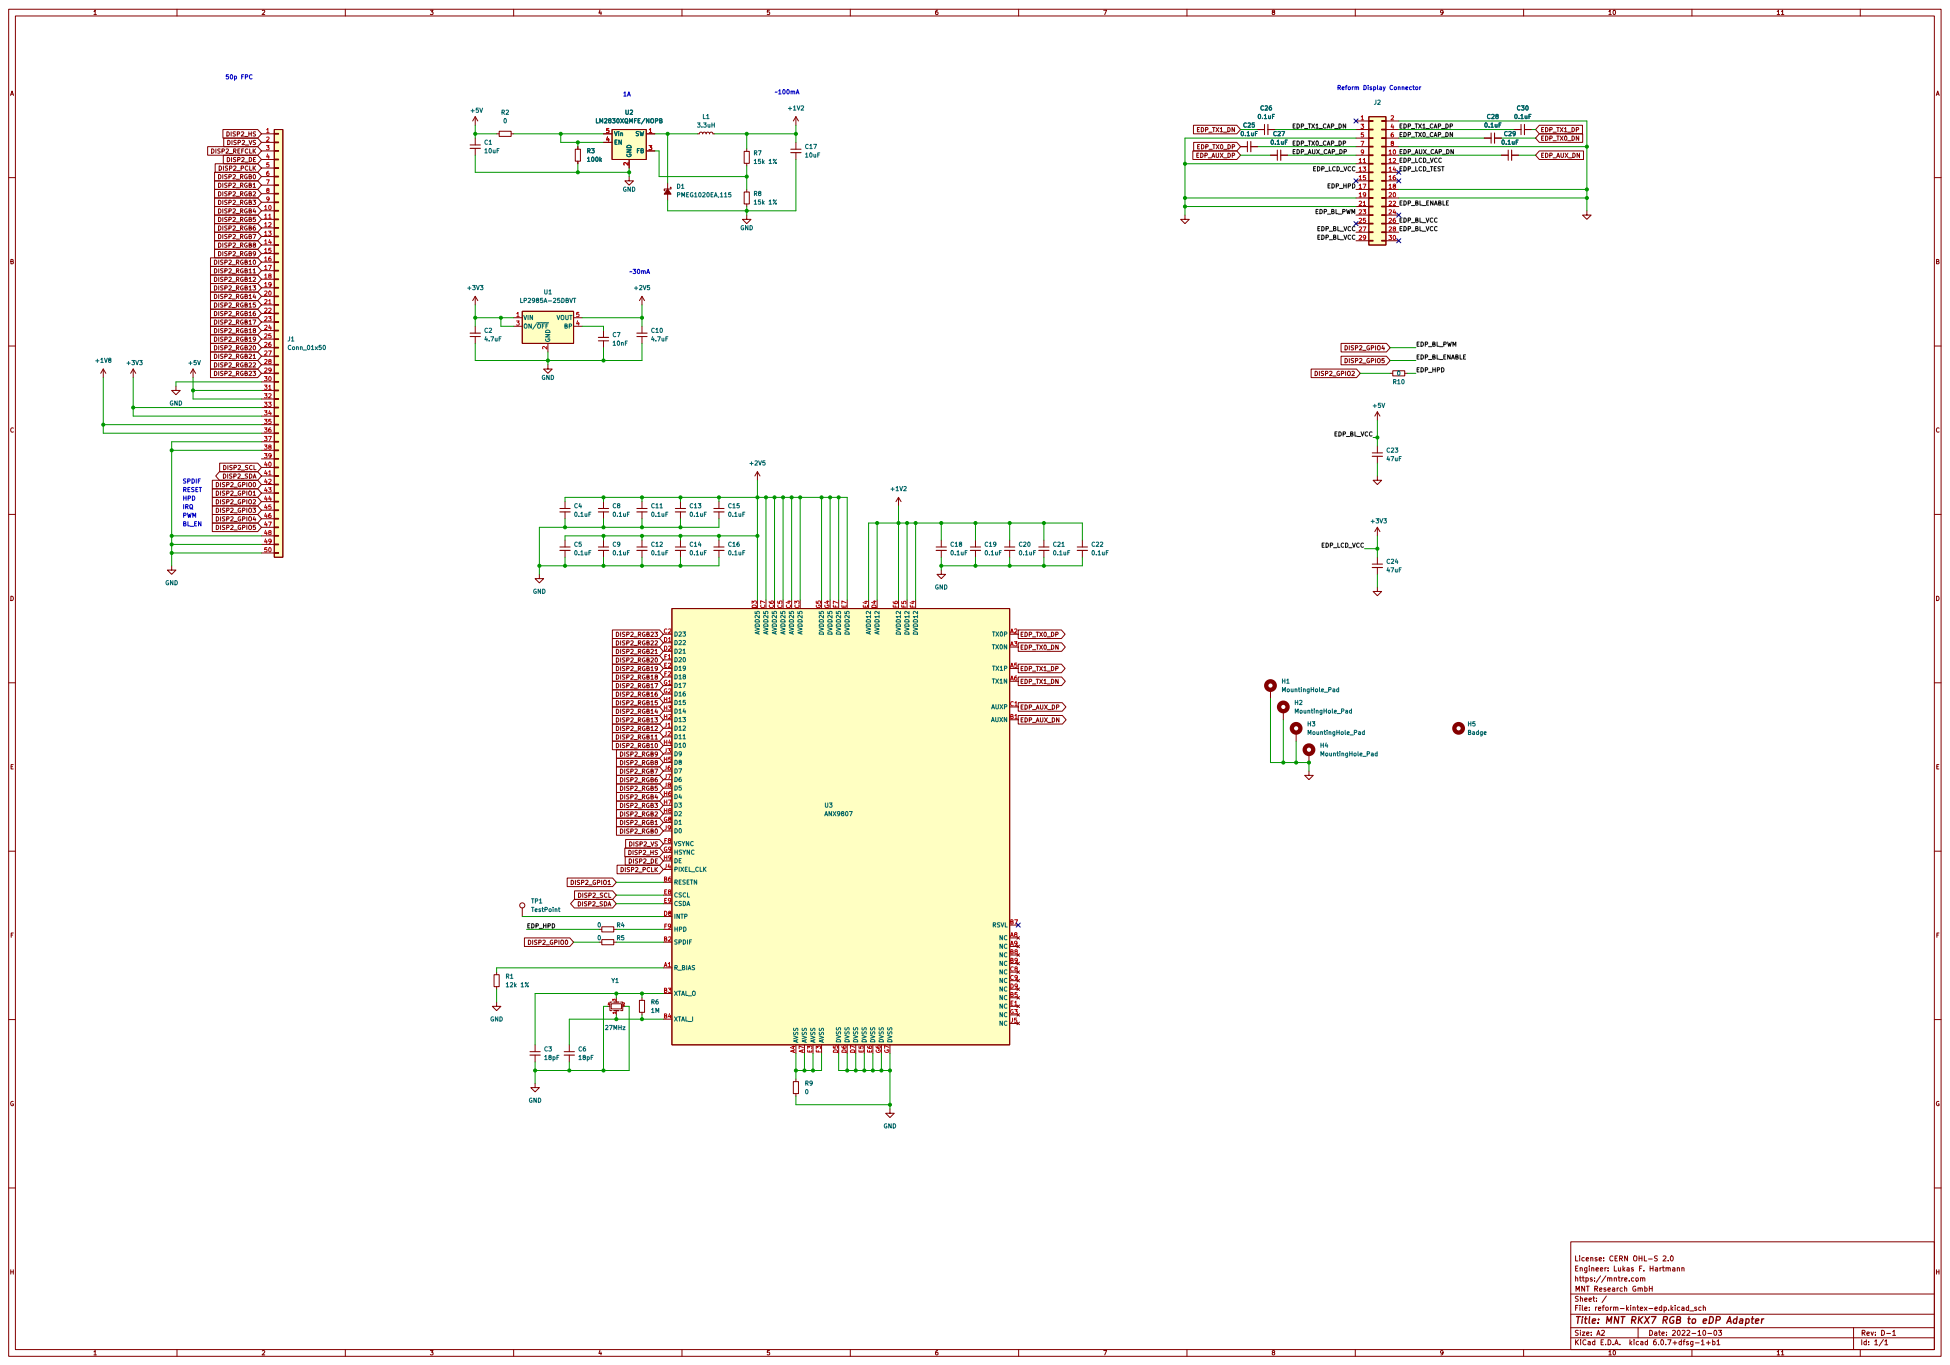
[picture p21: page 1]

EDP_TX1_CAP_DP
EDP_TX0_CAP_DN | 0.1uF

License: CERN OHL-S 2.0
Engineer: Lukas F. Hartmann
https://mntre.com
File: reform-kintex-edp.kicad_sch Sheet: / MNT Research GmbH

Id: 1/1 Title: MNT RKX7 RGB to eDP Adapter

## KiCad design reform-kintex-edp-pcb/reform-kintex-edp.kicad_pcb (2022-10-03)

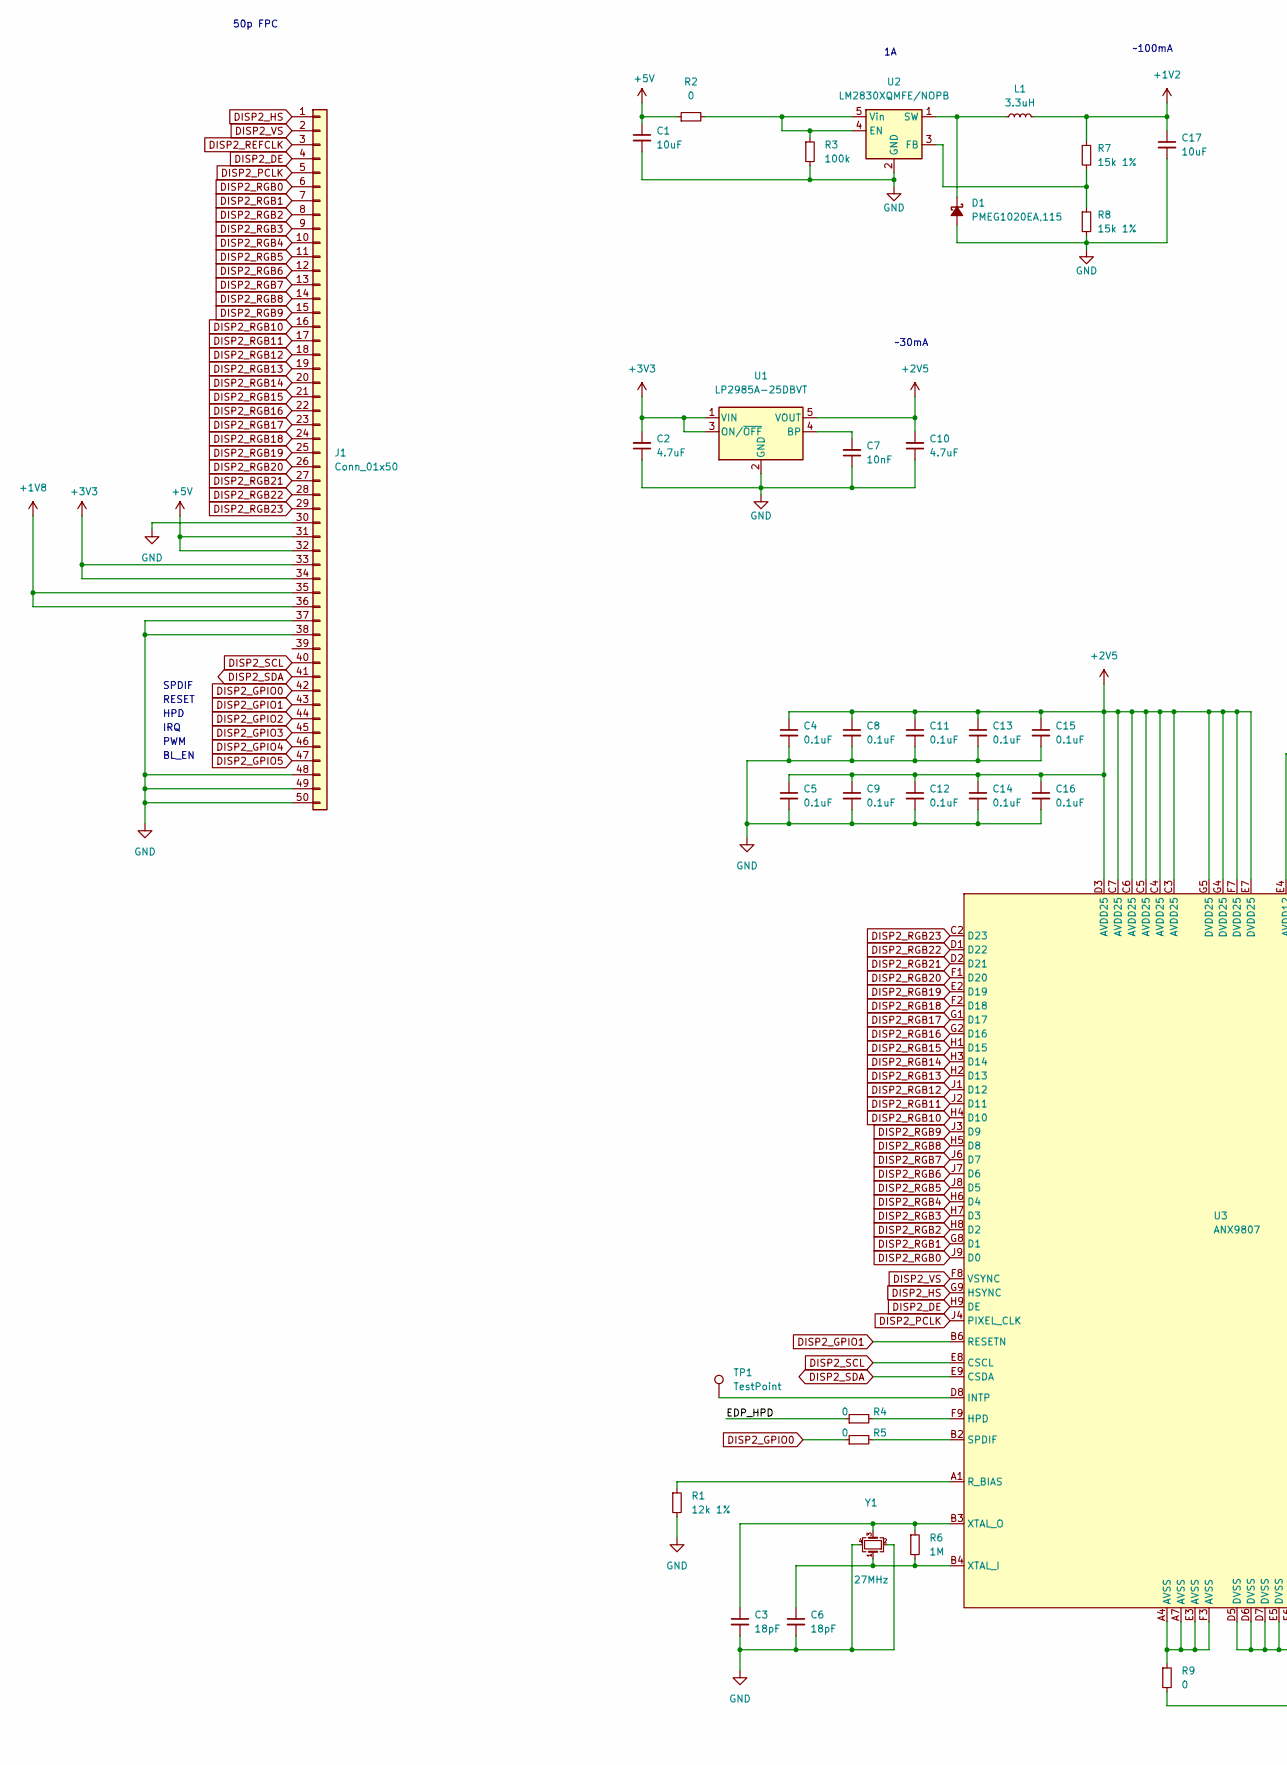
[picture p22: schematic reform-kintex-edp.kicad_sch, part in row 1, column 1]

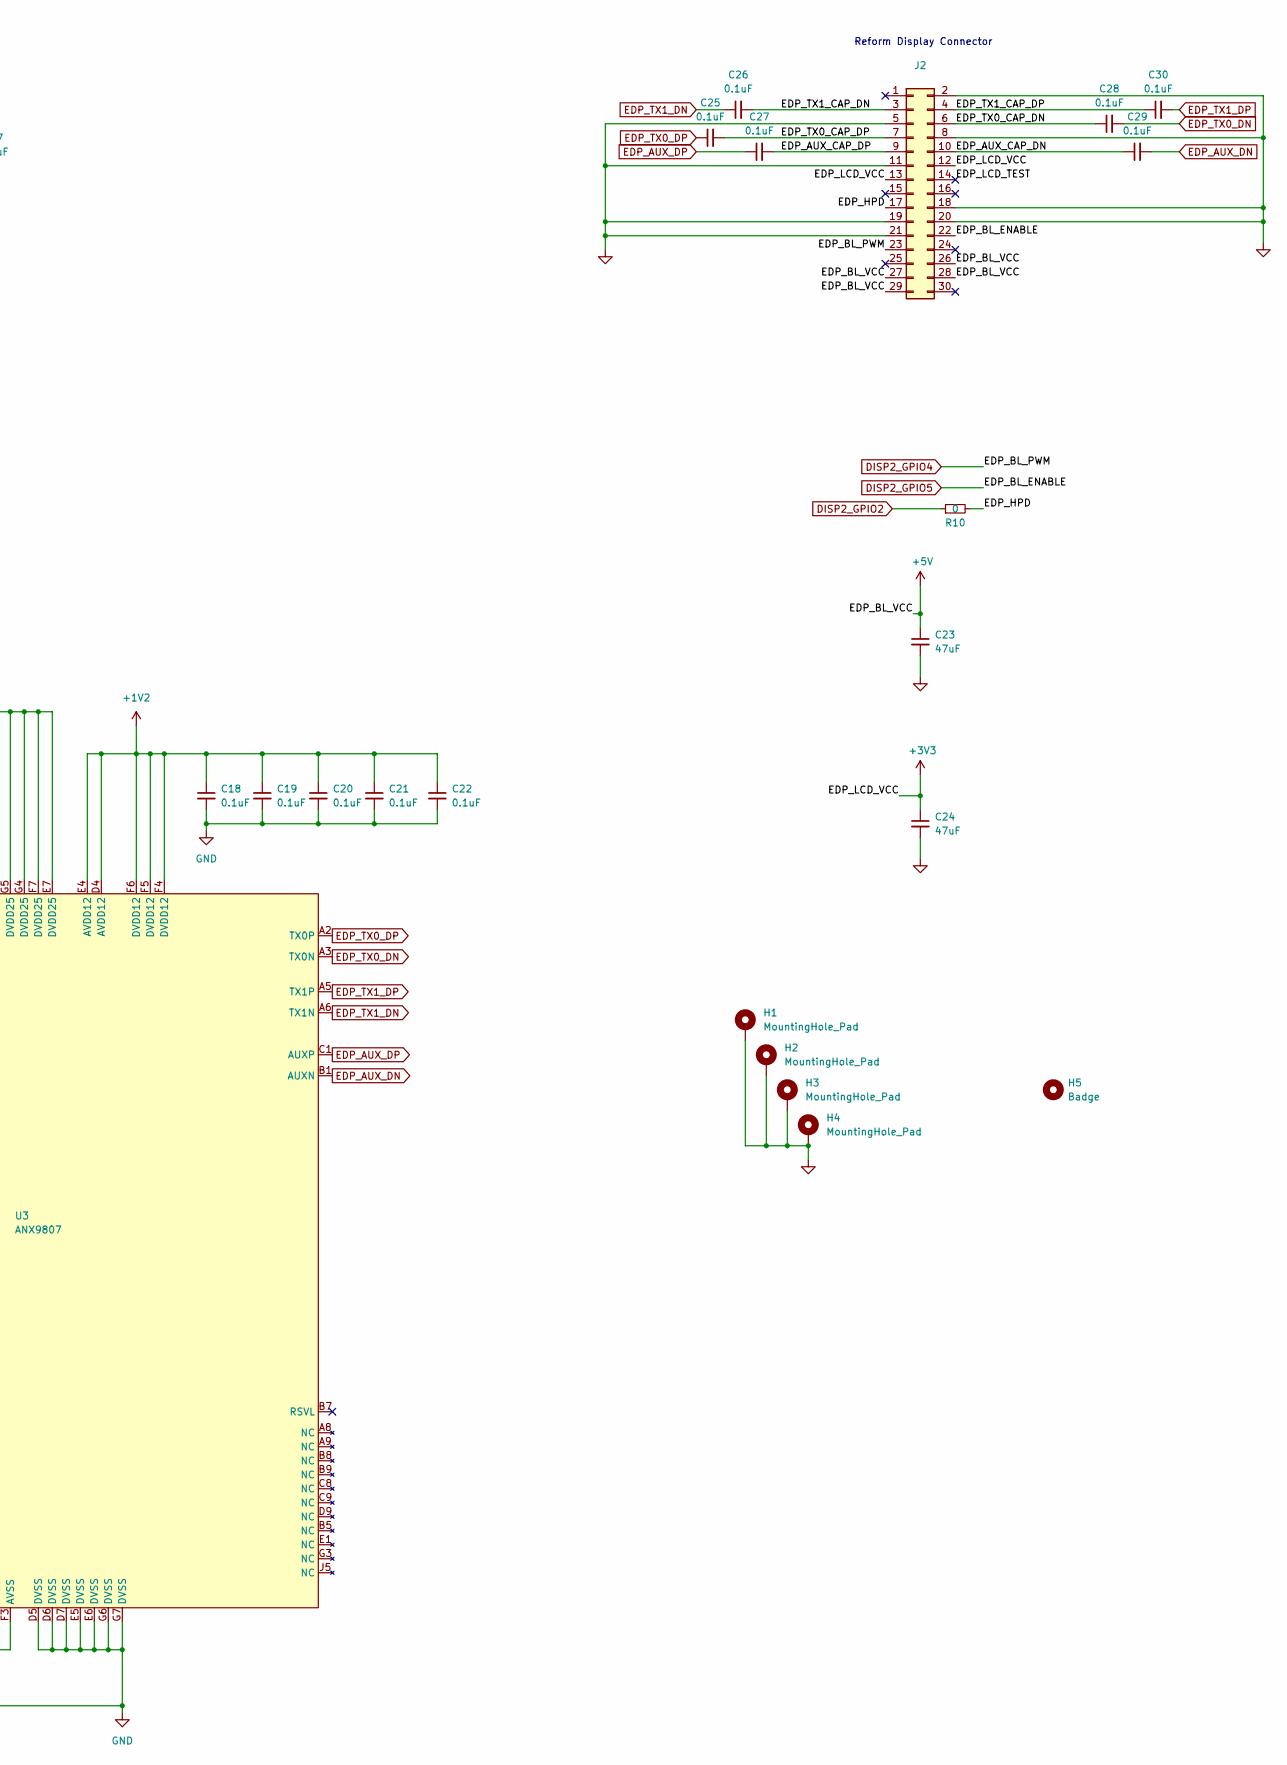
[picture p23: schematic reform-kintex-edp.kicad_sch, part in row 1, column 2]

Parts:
C1, C17: 10uF; C_0603_1608Metric; LCSC C86295
C2, C10: 4.7uF; C_0603_1608Metric
C3, C6: 18pF; C_0603_1608Metric
C4, C5, C8, C9, C11, C12, C13, C14, C15, C16, C18, C19, C20, C21, C22, C25, C26, C27, C28, C29, C30: 0.1uF; C_0402_1005Metric
C7: 10nF; C_0603_1608Metric
C23, C24: 47uF; C_0805_2012Metric
D1: PMEG1020EA,115; D_SOD-323; LCSC C426863
H1, H2, H3, H4: MountingHole_Pad; MountingHole_2.2mm_M2_DIN965_Pad
H5: Badge; mnt-rgb-edp-badge
J1: Conn_01x50; Hirose_FH12-50S-0.5SH_1x50-1MP_P0.50mm_Horizontal
J2: PinHeader_2x15_P2.00mm_Vertical
L1: 3.3uH; L_1210_3225Metric; LCSC C337905
R1: 12k 1%; R_0603_1608Metric
R2, R4, R5, R9, R10: 0; R_0603_1608Metric; LCSC C242160
R3: 100k; R_0603_1608Metric; LCSC C60491
R6: 1M; R_0603_1608Metric
R7, R8: 15k 1%; R_0603_1608Metric
TP1: TestPoint; TestPoint_Pad_D1.0mm
U1: LP2985A-25DBVT; SOT-23-5
U2: LM2830XQMFE/NOPB; SOT-23-5; LCSC C2072452
U3: ANX9807; BGA-ANX-81
Y1: 27MHz; Crystal_SMD_3225-4Pin_3.2x2.5mm; MPN FL2700102Z

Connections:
+1V2: C17.1, C18.1, C19.1, C20.1, C21.1, C22.1, L1.2, R7.1, U3.D4 (AVDD12), U3.E4 (AVDD12), U3.F4 (DVDD12), U3.F5 (DVDD12), U3.F6 (DVDD12)
+1V8: J1.35, J1.36
+2V5: C4.1, C5.1, C8.1, C9.1, C10.2, C11.1, C12.1, C13.1, C14.1, C15.1, C16.1, U1.5 (VOUT), U3.C3 (AVDD25), U3.C4 (AVDD25), U3.C5 (AVDD25), U3.C6 (AVDD25), U3.C7 (AVDD25), U3.D3 (AVDD25), U3.E7 (DVDD25), U3.F7 (DVDD25), U3.G4 (DVDD25), U3.G5 (DVDD25)
+3V3: C2.2, C24.1, J1.33, J1.34, J2.12, J2.13, U1.1 (VIN), U1.3 (ON/~OFF)
+5V: C1.1, C23.1, J1.31, J1.32, J2.26, J2.27, J2.28, J2.29, R2.1
/EDP_AUX_CAP_DN: C29.1, J2.10
/EDP_AUX_CAP_DP: C27.2, J2.9
/EDP_HPD: J2.17, R4.1, R10.2
/EDP_LCD_TEST: J2.14
/EDP_TX0_CAP_DN: C28.1, J2.6
/EDP_TX0_CAP_DP: C25.2, J2.7
/EDP_TX1_CAP_DN: C26.2, J2.3
/EDP_TX1_CAP_DP: C30.1, J2.4
DISP2_DE: J1.4, U3.H9 (DE)
DISP2_GPIO0: J1.42, R5.1
DISP2_GPIO1: J1.43, U3.B6 (RESETN)
DISP2_GPIO2: J1.44, R10.1
DISP2_GPIO3: J1.45
DISP2_GPIO4: J1.46, J2.23
DISP2_GPIO5: J1.47, J2.22
DISP2_HS: J1.1, U3.G9 (HSYNC)
DISP2_PCLK: J1.5, U3.J4 (PIXEL_CLK)
DISP2_REFCLK: J1.3
DISP2_RGB0: J1.6, U3.J9 (D0)
DISP2_RGB1: J1.7, U3.G8 (D1)
DISP2_RGB2: J1.8, U3.H8 (D2)
DISP2_RGB3: J1.9, U3.H7 (D3)
DISP2_RGB4: J1.10, U3.H6 (D4)
DISP2_RGB5: J1.11, U3.J8 (D5)
DISP2_RGB6: J1.12, U3.J7 (D6)
DISP2_RGB7: J1.13, U3.J6 (D7)
DISP2_RGB8: J1.14, U3.H5 (D8)
DISP2_RGB9: J1.15, U3.J3 (D9)
DISP2_RGB10: J1.16, U3.H4 (D10)
DISP2_RGB11: J1.17, U3.J2 (D11)
DISP2_RGB12: J1.18, U3.J1 (D12)
DISP2_RGB13: J1.19, U3.H2 (D13)
DISP2_RGB14: J1.20, U3.H3 (D14)
DISP2_RGB15: J1.21, U3.H1 (D15)
DISP2_RGB16: J1.22, U3.G2 (D16)
DISP2_RGB17: J1.23, U3.G1 (D17)
DISP2_RGB18: J1.24, U3.F2 (D18)
DISP2_RGB19: J1.25, U3.E2 (D19)
DISP2_RGB20: J1.26, U3.F1 (D20)
DISP2_RGB21: J1.27, U3.D2 (D21)
DISP2_RGB22: J1.28, U3.D1 (D22)
DISP2_RGB23: J1.29, U3.C2 (D23)
DISP2_SCL: J1.40, U3.E8 (CSCL)
DISP2_SDA: J1.41, U3.E9 (CSDA)
DISP2_VS: J1.2, U3.F8 (VSYNC)
EDP_AUX_DN: C29.2, U3.B1 (AUXN)
EDP_AUX_DP: C27.1, U3.C1 (AUXP)
EDP_TX0_DN: C28.2, U3.A3 (TX0N)
EDP_TX0_DP: C25.1, U3.A2 (TX0P)
EDP_TX1_DN: C26.1, U3.A6 (TX1N)
EDP_TX1_DP: C30.2, U3.A5 (TX1P)
unnamed: C3.1, R6.1, U3.B3 (XTAL_O), Y1.3
unnamed: C6.1, R6.2, U3.B4 (XTAL_I), Y1.1
unnamed: C7.2, U1.4 (BP)
unnamed: D1.1 (K), L1.1, U2.1 (SW)
unnamed: R1.1, U3.A1 (R_BIAS)
unnamed: R2.2, R3.1, U2.4 (EN), U2.5 (Vin)
unnamed: R4.2, U3.F9 (HPD)
unnamed: R5.2, U3.B2 (SPDIF)
unnamed: R7.2, R8.1, U2.3 (FB)
unnamed: R9.1, U3.A4 (AVSS), U3.A7 (AVSS), U3.E3 (AVSS), U3.F3 (AVSS)
unnamed: TP1.1, U3.D8 (INTP)

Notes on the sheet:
BL_EN
~30mA
PWM
IRQ
~100mA
50p FPC
SPDIF
RESET
Reform Display Connector
HPD

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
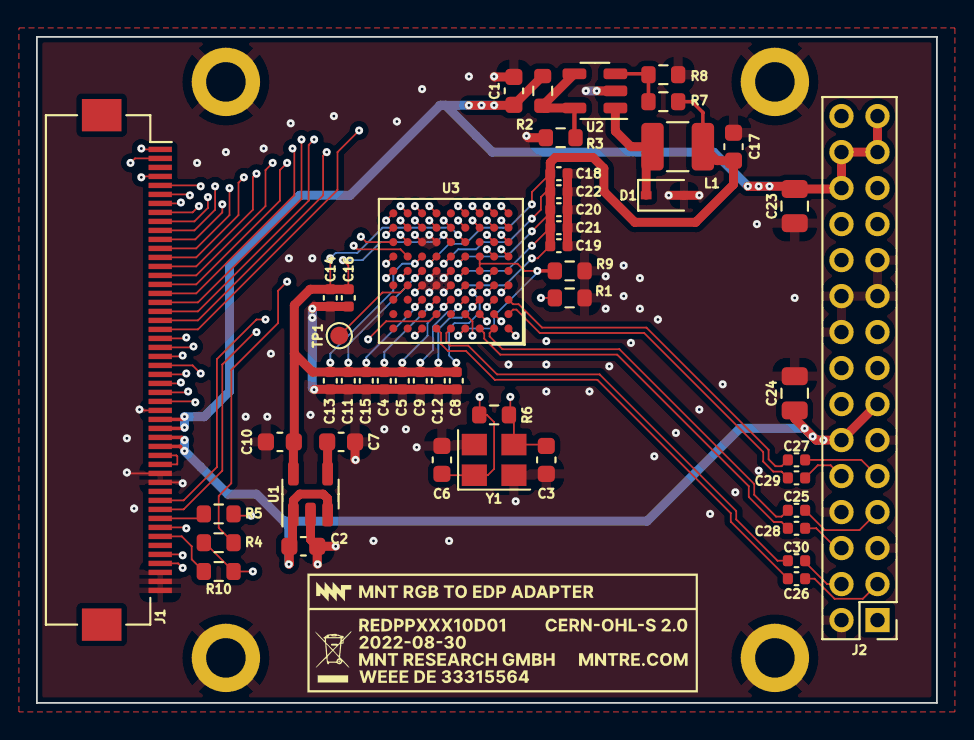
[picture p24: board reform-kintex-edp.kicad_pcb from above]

Board: 4 copper layers, 50.0 x 37.0 mm, 54 parts (0 on the bottom side), 65 nets.

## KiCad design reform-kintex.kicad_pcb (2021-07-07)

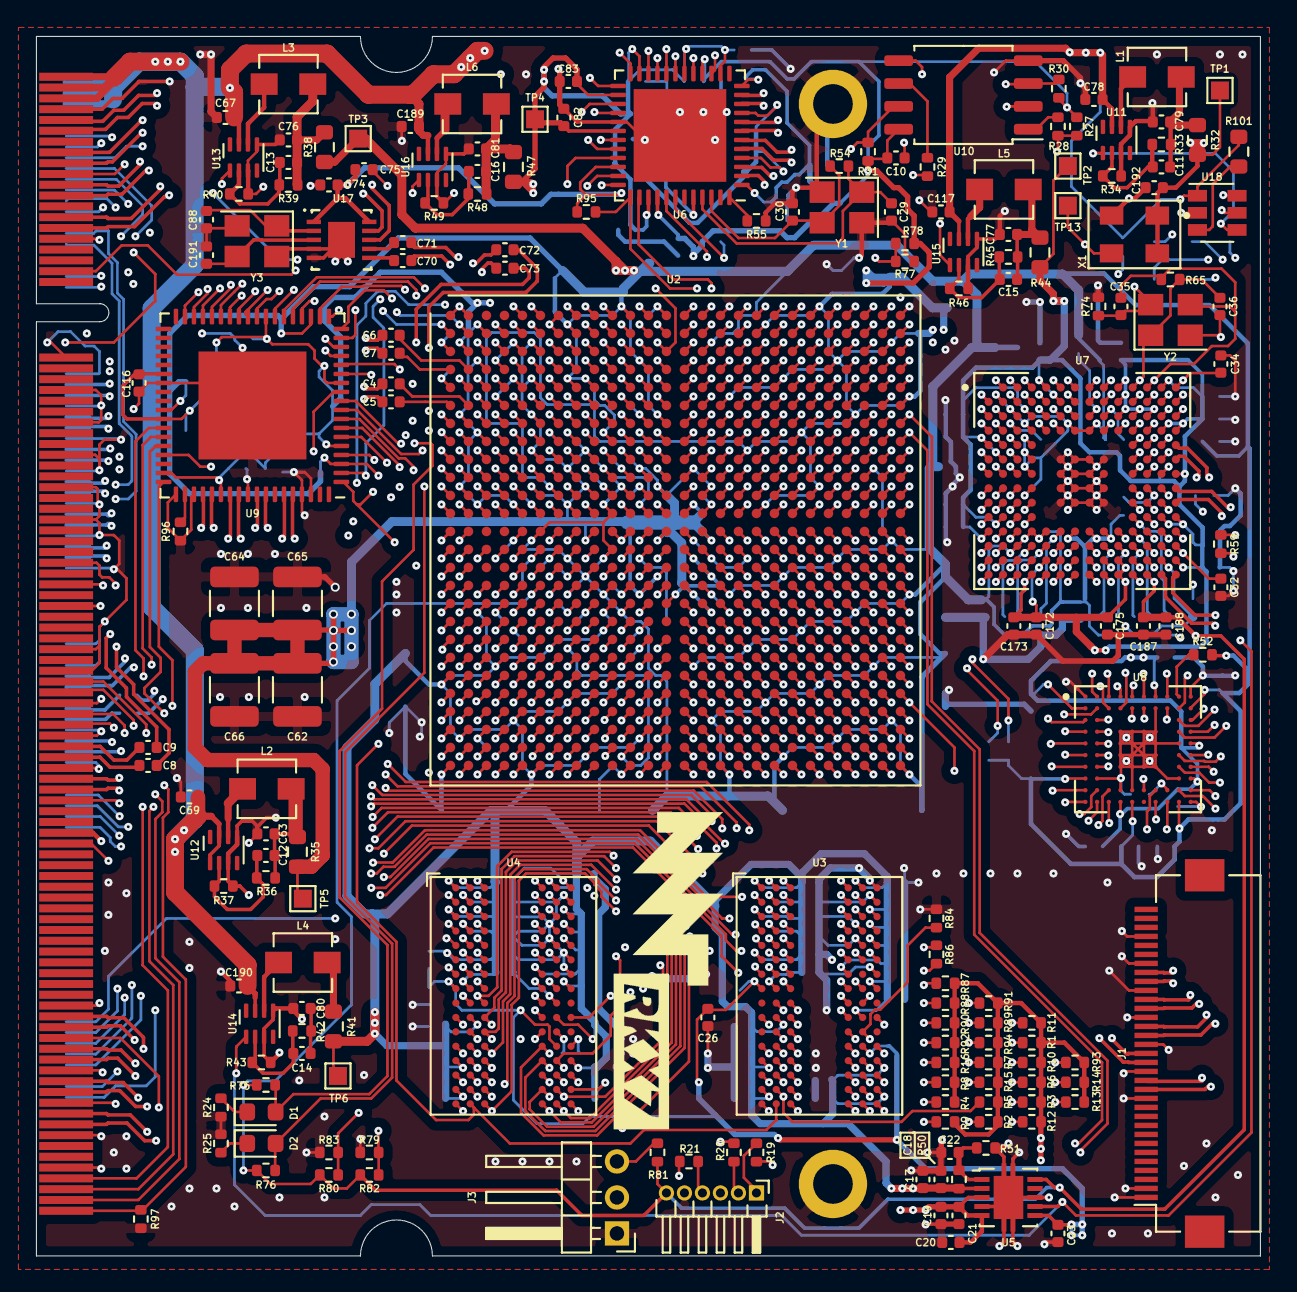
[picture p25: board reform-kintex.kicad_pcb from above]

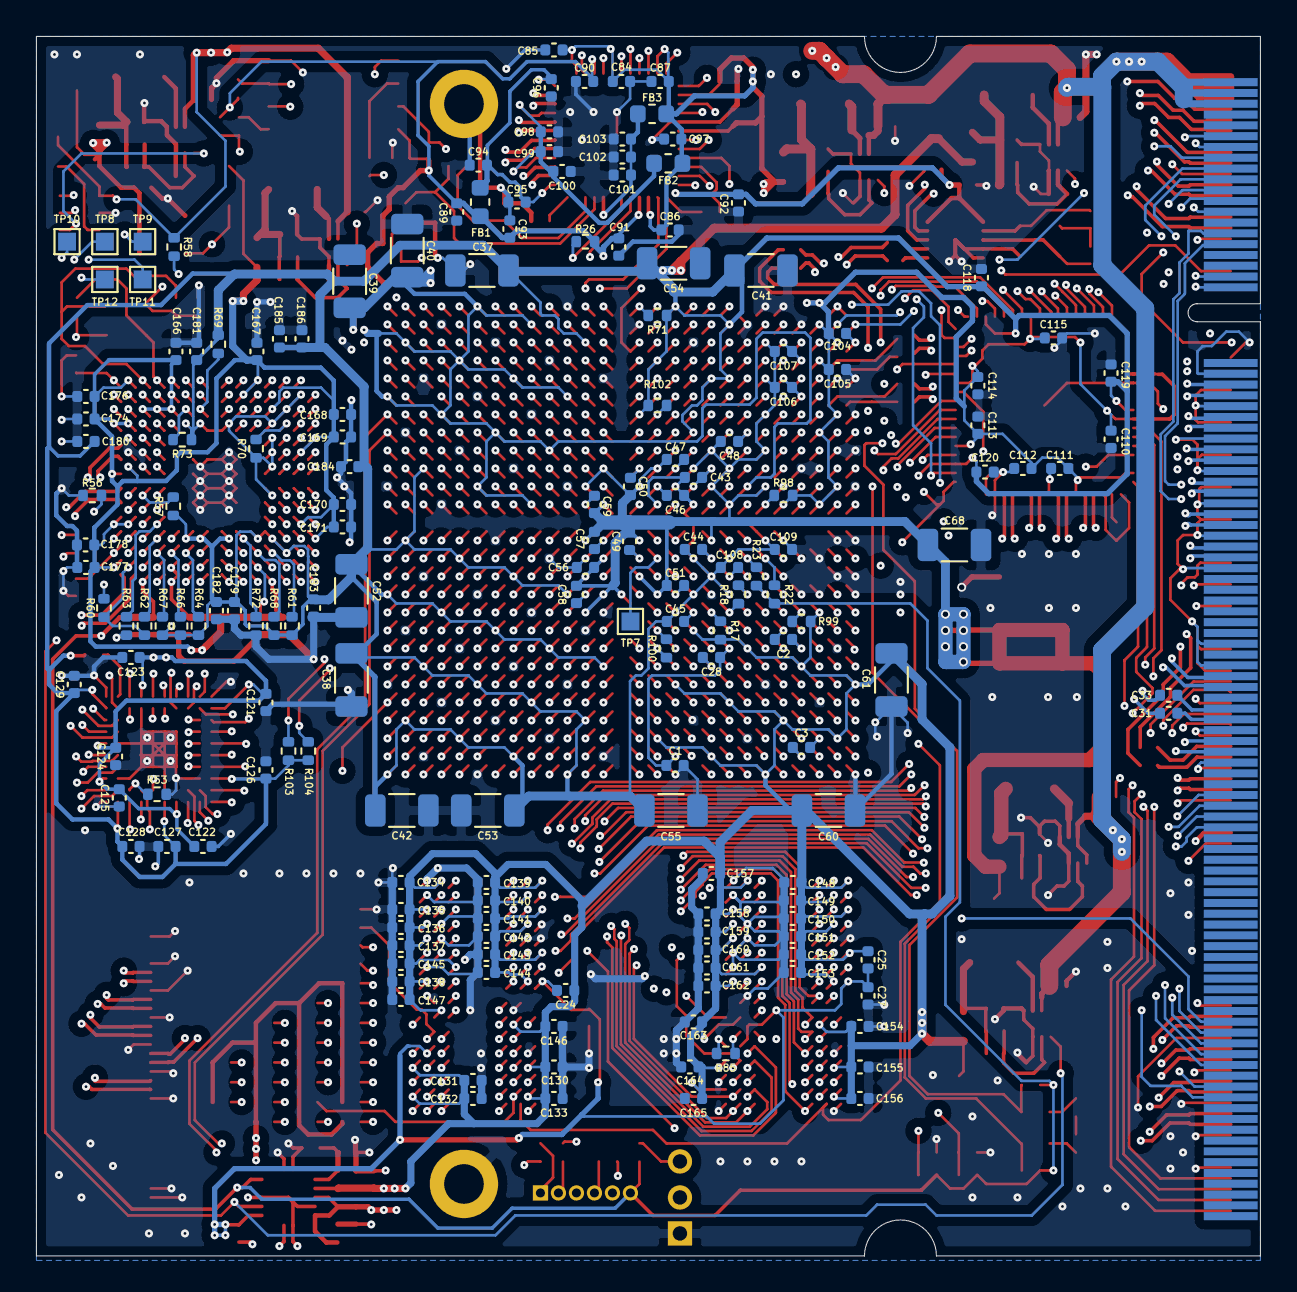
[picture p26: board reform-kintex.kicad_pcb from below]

Board: 8 copper layers, 68.0 x 67.8 mm, 348 parts (170 on the bottom side), 416 nets.

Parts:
C1, C2, C3, C4, C5, C6, C7, C8, C9, C10, C23, C28, C31, C33, C70, C71, C72, C73, C74, C83, C84, C85, C86, C87, C90, C91, C92, C95, C96, C99, C100, C102, C110, C111, C112, C113, C114, C115, C116, C118, C119, C120, C121, C122, C123, C124, C125, C126, C127, C128, C129, C130, C131, C132, C133, C134, C135, C136, C137, C138, C139, C140, C141, C142, C143, C144, C145, C146, C147, C148, C149, C150, C151, C152, C153, C154, C155, C156, C157, C158, C159, C160, C161, C162, C163, C164, C165, C167, C168, C169, C170, C171, C172, C173, C174, C175, C176, C177, C178, C180, C181, C182, C183, C184, C185, C186, C188, C192: 0.1uF; C_0402_1005Metric
C11, C12, C13, C14, C15, C16: 120p; C_0402_1005Metric
C17, C18, C19, C20, C21, C63, C76, C77, C79, C80, C81, C82, C89, C93, C94, C97, C98, C101: 10uF; C_0402_1005Metric
C22: 1nF; C_0402_1005Metric
C24, C25, C26, C27, C103: 10nF; C_0402_1005Metric
C29, C30, C35, C36, C88, C191: 22pF; C_0402_1005Metric
C32, C34: 4.7nF; C_0402_1005Metric
C37, C38, C39, C40, C41, C42, C60, C61, C68: 100uF; C_1206_3216Metric
C43, C44, C45, C46, C47, C48, C49, C50, C51, C56, C57, C58, C59, C67, C69, C75, C78, C104, C105, C106, C107, C108, C109, C117, C189, C190: 4.7uF; C_0402_1005Metric
C52, C53, C54, C55: 47uF; C_1206_3216Metric
C62, C64, C65, C66: 220uF; C_1210_3225Metric
C166, C179, C187: 1uF; C_0402_1005Metric
D1, D2: LED_Small; LED_0603_1608Metric
FB1, FB2, FB3: Ferrite_Bead_Small; L_0603_1608Metric
GFX1: MountingHole; mnt-rkx7
H1, H2: MountingHole_Pad; MountingHole_2.2mm_M2_DIN965_Pad
J1: Conn_01x33; Hirose_FH12-33S-0.5SH_1x33-1MP_P0.50mm_Horizontal
J2: JTAG_01x06; PinHeader_1x06_P1.00mm_Horizontal
J3: Conn_01x03_Male; PinHeader_1x03_P2.00mm_Horizontal
L1, L2, L3, L4, L5, L6: IHLP1212AEERR47M11; L_Vishay_IHLP-1212
R1, R2, R3, R4, R5, R6, R7, R8, R9, R10, R11, R12, R13, R14, R15, R16, R87, R88, R89, R90, R91, R92, R93, R94: 40; R_0402_1005Metric
R17, R18, R86, R99, R100: 80.6; R_0402_1005Metric
R19, R20, R21, R77, R98: 100; R_0402_1005Metric
R22, R26, R75, R95: 4.7k; R_0402_1005Metric
R23: ???; R_0402_1005Metric
R24, R25: 200; R_0402_1005Metric
R27: 2k2; R_0402_1005Metric
R28, R29, R79, R80, R81: 0; R_0402_1005Metric
R30, R31, R71, R102, R103, R104: 4k7; R_0402_1005Metric
R32, R35, R38, R41, R44, R47, R101: 0; R_0603_1608Metric
R33: 453k; R_0402_1005Metric
R34, R37, R40, R43, R46, R49: 100k_1%; R_0402_1005Metric
R36: 66.5k; R_0402_1005Metric
R39: 200k; R_0402_1005Metric
R42: 150k; R_0402_1005Metric
R45: 83.5k; R_0402_1005Metric
R48: 100k; R_0402_1005Metric
R50, R51, R52, R53, R56, R57, R97: 10k; R_0402_1005Metric
R54, R65: 1.8M; R_0402_1005Metric
R55: 12.1k; R_0402_1005Metric
R58: 90.9k 1%; R_0402_1005Metric
R59, R60: 10k 1%; R_0402_1005Metric
R61, R62, R63, R64, R66, R67, R68, R69, R70, R72, R73, R74, R78, R82, R83: DNP; R_0402_1005Metric
R76: 330; R_0402_1005Metric
R84, R85: 240 1%; R_0402_1005Metric
R96: 5.1k; R_0402_1005Metric
TP1, TP2, TP3, TP4, TP5, TP6, TP7, TP13: TestPoint; TestPoint_Pad_1.0x1.0mm
TP8: TUSBJ_TCK; TestPoint_Pad_1.0x1.0mm
TP9: TUSBJ_TMS; TestPoint_Pad_1.0x1.0mm
TP10: TUSBJ_TDI; TestPoint_Pad_1.0x1.0mm
TP11: TUSBJ_TRSTN; TestPoint_Pad_1.0x1.0mm
TP12: TUSBJ_TDO; TestPoint_Pad_1.0x1.0mm
U1: MNT Reform 2.0 SoM Socket; ddr2-sodimm200
U2: XC7K160T-FFG676; Xilinx_FFG676
U3, U4: IS43TR16512B-125KBLI; BGA-96_9.0x13.0mm_Layout2x3x16_P0.8mm
U5: TPS51200DRC; VSON-10-1EP_3x3mm_P0.5mm_EP1.65x2.4mm
U6: KSZ9031RNXCA; QFN-48-1EP_7x7mm_P0.5mm_EP5.15x5.15mm
U7: TUSB1310ZAY; BGA175C80P14X14_1200X1200X140
U8: TC358778XBG; BGA80C65P10X10_700X700X100
U9: SiI9022A; QFN-72-1EP_10x10mm_P0.5mm_EP6x6mm
U10: W25Q128JVS; SOIC-8_5.23x5.23mm_P1.27mm
U11, U12, U13, U14, U15, U16: TPS62823DLC; Texas_VSON-HR-8_1.5x2mm_P0.5mm
U17: Si52112-B5-GM2; Silicon_Labs-Si52112-B5-GM2-Level_B
U18: LM3880; SOT-23-6
X1: ASFLMB-100.000MHZ-XY-T; OSCDFN500X320X90-4N
Y1, Y3: ABM8G-25.000MHZ-18-D2Y-T; Crystal_SMD_3225-4Pin_3.2x2.5mm
Y2: ABM8G-20.000MHZ-18-D2Y-T; Crystal_SMD_3225-4Pin_3.2x2.5mm

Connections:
+1V0: C47.2, C48.2, C49.2, C50.2, C51.2, C56.2, C57.2, C58.2, C59.2, C62.2, C64.2, C65.2, C66.2, C68.2, C106.2, C107.2, R35.1, TP5.1, U2.C6, U2.E6, U2.G6, U2.J6, U2.J9, U2.K8, U2.K10, U2.K12, U2.K14, U2.L6, U2.L9, U2.L13, U2.L15, U2.M8, U2.M14, U2.N9, U2.N13, U2.N15, U2.P14, U2.R13, U2.R15, U2.T12, U2.T14, U2.U13, U2.U15
+1V1: C166.1, C167.1, C168.1, C169.1, C170.1, C171.1, C172.1, C173.1, C174.1, C175.1, C176.1, C177.1, C178.1, R44.1, TP2.1, U7.A5, U7.A10, U7.A13, U7.B6, U7.B10, U7.C4, U7.C10, U7.C11, U7.C12, U7.D13, U7.D14, U7.E1, U7.F2, U7.G13, U7.G14, U7.K2, U7.K13, U7.K14, U7.L1, U7.N5, U7.N10, U7.N14, U7.P4, U7.P10
+1V2: C82.2, C83.2, C84.2, C85.2, C86.2, C87.2, C97.2, C104.2, C105.2, C110.1, C111.1, C112.1, C113.1, C114.1, C115.1, C116.1, C121.1, C122.1, C123.1, C124.1, C125.1, FB2.2, FB3.2, R47.1, R98.2, TP4.1, U2.B3, U2.C2, U2.D3, U2.G2, U2.H3, U2.L2, U2.M3, U2.M5, U6.14, U6.18, U6.23, U6.26, U6.30, U6.39, U8.A7, U8.B1, U8.E10, U8.H10, U8.K4, U9.5, U9.12, U9.26, U9.42, U9.47, U9.53, U9.60
+1V5: C17.1, C18.1, C24.1, C25.1, C60.2, C61.2, C130.1, C131.1, C132.1, C133.1, C134.1, C135.1, C136.1, C137.1, C138.1, C139.1, C140.1, C141.1, C142.1, C143.1, C144.1, C145.1, C146.1, C147.1, C148.1, C149.1, C150.1, C151.1, C152.1, C153.1, C154.1, C155.1, C156.1, C157.1, C158.1, C159.1, C160.1, C161.1, C162.1, C163.1, C164.1, C165.1, R17.2, R41.1, R50.1, R99.2, TP6.1, U2.AA1, U2.AA11, U2.AB8, U2.AC5, U2.AD2, U2.AD12, U2.AE9, U2.AF6, U2.U3, U2.V10, U2.W7, U2.Y4, U3.A1, U3.A8, U3.B2, U3.C1, U3.C9, U3.D2, U3.D9, U3.E9, U3.F1, U3.G7, U3.H2, U3.H9, U3.K2, U3.K8, U3.N1, U3.N9, U3.R1, U3.R9, U4.A1, U4.A8, U4.B2, U4.C1, U4.C9, U4.D2, U4.D9, U4.E9, U4.F1, U4.G7, U4.H2, U4.H9, U4.K2, U4.K8, U4.N1, U4.N9, U4.R1, U4.R9, U5.2
+1V8: C37.2, C38.2, C41.2, C42.2, C43.2, C44.2, C45.2, C46.2, C52.2, C53.2, C54.2, C55.2, C108.2, C109.2, C118.1, C119.1, C120.1, C126.1, C127.1, C128.1, C129.1, C179.1, C180.1, C181.1, C182.1, C183.1, C184.1, C185.1, C186.1, R38.1, R52.1, R57.1, R61.1, R63.1, R64.1, R66.1, R67.1, R68.1, R69.1, R70.1, R71.1, R73.1, R102.1, R103.1, R104.1, TP3.1, U2.A11, U2.AA21, U2.AB18, U2.AC15, U2.AC25, U2.AD22, U2.AE19, U2.AF16, U2.AF26, U2.B8, U2.C15, U2.D12, U2.E8, U2.E9, U2.G13, U2.H10, U2.K24, U2.L11, U2.M10, U2.M12, U2.N6, U2.N25, U2.P8, U2.P10, U2.P22, U2.R9, U2.R19, U2.T8, U2.T10, U2.T16, U2.T26, U2.U11, U2.U23, U2.V20, U2.W17, U2.Y14, U2.Y24, U7.B2, U7.C3, U7.D4, U7.D7, U7.D8, U7.D9, U7.E4, U7.F4, U7.G4, U7.H4, U7.L4, U7.L5, U7.L7, U7.L8, U7.L9, U7.M3, U8.B10, U8.H1, U8.K5, U8.K9, U9.3, U9.21, U9.46
+3V3: C10.1, C39.2, C40.2, C74.2, C75.2, C89.2, C90.2, C91.2, C92.2, C93.2, C187.1, C188.1, C192.1, FB1.2, J2.6, R22.1, R23.1, R26.1, R27.1, R30.1, R31.1, R32.1, R75.1, R76.1, R77.1, R79.1, R80.1, R81.1, R95.1, TP1.1, U2.A21, U2.B18, U2.C25, U2.D22, U2.E19, U2.F16, U2.F26, U2.G23, U2.H20, U2.J17, U2.L7, U2.L21, U2.M18, U2.T6, U5.10, U6.16, U6.34, U6.40, U7.P12, U10.8, U17.1, U17.10, X1.1, X1.4
+5V: C67.2, C69.2, C78.2, C117.2, C189.2, C190.2, R58.2, R101.1, U1.1, U1.2, U1.3, U1.4, U1.5, U1.6, U11.7, U12.1, U12.7, U13.7, U14.7, U15.7, U16.7, U18.1
/RAM/PCIE2_GTX_CLK_HOST_N: C71.2, U2.D5
/RAM/PCIE2_GTX_CLK_HOST_P: C70.2, U2.D6
/RAM/PCIE2_GTX_CLK_N: C73.2, U2.F5
/RAM/PCIE2_GTX_CLK_P: C72.2, U2.F6
/RAM/USB1TXN: C31.2, U7.H14
/RAM/USB1TXP: C33.2, U7.J14
/RAM/USB2_GTX_N: C8.2, U2.B1
/RAM/USB2_GTX_P: C9.2, U2.B2
BACKLIGHT_EN: U1.105, U2.B16
BACKLIGHT_PWM: U1.164, U2.K16
CCLK: R29.2, U2.C8
CLK_100MHZ: TP13.1, U2.F22, X1.3
DAC_BCLK: U1.170, U2.L17
DAC_DIN: U1.166, U2.K17
DAC_DOUT: U1.178, U2.M17
DAC_MCLK: U1.176, U2.L18
DAC_RXFS: U1.168, U2.K18
DAC_SCL: U1.101, U2.H26
DAC_SDA: U1.103, U2.G26
DAC_TXFS: U1.172, U2.M16
DISP1_CLK: U2.C12, U9.22
DISP1_DE: U2.D10, U9.33
DISP1_HS: U2.D11, U9.34
DISP1_RGB0: U2.E10, U9.32
DISP1_RGB1: U2.D8, U9.31
DISP1_RGB2: U2.F9, U9.30
DISP1_RGB3: U2.F8, U9.29
DISP1_RGB4: U2.A9, U9.28
DISP1_RGB5: U2.A8, U9.27
DISP1_RGB6: U2.B9, U9.25
DISP1_RGB7: U2.D9, U9.24
DISP1_RGB8: U2.F14, U9.23
DISP1_RGB9: U2.C9, U9.20
DISP1_RGB10: U2.G14, U9.19
DISP1_RGB11: U2.F10, U9.18
DISP1_RGB12: U2.H14, U9.17
DISP1_RGB13: U2.G11, U9.16
DISP1_RGB14: U2.H11, U9.15
DISP1_RGB15: U2.G9, U9.14
DISP1_RGB16: U2.H13, U9.13
DISP1_RGB17: U2.G10, U9.11
DISP1_RGB18: U2.J13, U9.10
DISP1_RGB19: U2.H12, U9.9
DISP1_RGB20: U2.J10, U9.8
DISP1_RGB21: U2.H8, U9.7
DISP1_RGB22: U2.H9, U9.6
DISP1_RGB23: U2.J11, U9.4
DISP1_SCL: R102.2, U1.107, U2.G12, U9.1
DISP1_SDA: R71.2, U1.109, U2.A13, U9.2
DISP1_VS: U2.E11, U9.35
DISP2_DE: U2.AA15, U8.J7
DISP2_HS: U2.AB15, U8.K8
DISP2_PCLK: U2.AC18, U8.J6
DISP2_RGB0: U2.AF15, U8.J3
DISP2_RGB1: U2.AF14, U8.K3
DISP2_RGB2: U2.AE16, U8.J2
DISP2_RGB3: U2.AE15, U8.K2
DISP2_RGB4: U2.AE17, U8.J1
DISP2_RGB5: U2.AF17, U8.K1
DISP2_RGB6: U2.AA14, U8.G2
DISP2_RGB7: U2.AF18, U8.G1
DISP2_RGB8: U2.AD15, U8.F2
DISP2_RGB9: U2.AE18, U8.F1
DISP2_RGB10: U2.AD16, U8.E2
DISP2_RGB11: U2.AF19, U8.E1
DISP2_RGB12: U2.AC16, U8.D2
DISP2_RGB13: U2.AD14, U8.D1
DISP2_RGB14: U2.AC17, U8.C2
DISP2_RGB15: U2.AC14, U8.C1
DISP2_RGB16: U2.AB14, U8.B2
DISP2_RGB17: U2.AA17, U8.A2
DISP2_RGB18: U2.Y15, U8.B3
DISP2_RGB19: U2.AA18, U8.A3
DISP2_RGB20: U2.Y16, U8.B4
DISP2_RGB21: U2.AB17, U8.A4
DISP2_RGB22: U2.AF20, U8.B5
DISP2_RGB23: U2.AD20, U8.A5
DISP2_SCL: R104.2, U2.Y26, U8.A8
DISP2_SDA: R103.2, U2.W26, U8.B8
DISP2_VS: U2.AB16, U8.K7
DSI_CLK_N: J1.19, U8.F10
DSI_CLK_P: J1.20, U8.F9
DSI_D0_N: J1.25, U8.J10
DSI_D0_P: J1.26, U8.J9
DSI_D1_N: J1.22, U8.G10
DSI_D1_P: J1.23, U8.G9
DSI_D2_N: J1.16, U8.D10
DSI_D2_P: J1.17, U8.D9
DSI_D3_N: J1.13, U8.C10
DSI_D3_P: J1.14, U8.C9
DSI_RST_N: U2.AB26, U8.B9
EDP_RESETn: U1.38, U2.C14
EN_VAUX: U15.1, U18.6
EN_VDDR: U5.7, U14.1, U18.5
EN_VIO: U11.1, U13.1, U16.1, U18.4
ETH0_A+: U1.29, U6.2
ETH0_A-: U1.27, U6.3
ETH0_B+: U1.23, U6.5
ETH0_B-: U1.21, U6.6
ETH0_C+: U1.17, U6.7
ETH0_C-: U1.15, U6.8
ETH0_D+: U1.11, U6.10
ETH0_D-: U1.9, U6.11
ETH0_LED_LINK1: U1.83, U6.17
ETH0_LED_RX: U1.79, U6.15
ETH_INT_N: U2.E16, U6.38
ETH_MDC: U2.E17, U6.36
ETH_MDIO: R95.2, U2.E15, U6.37
ETH_REF_CLK: U2.F17, U6.41
ETH_RST_N: R26.2, U2.G17, U6.42
ETH_RX_CLK: U2.D18, U6.35
ETH_RX_D0: U2.J15, U6.32
ETH_RX_D1: U2.J16, U6.31
ETH_RX_D2: U2.F20, U6.28
ETH_RX_D3: U2.D20, U6.27
ETH_RX_DV: U2.F15, U6.33
ETH_TX_CLK: U2.E18, U6.24
ETH_TX_D0: U2.H18, U6.19
ETH_TX_D1: U2.H17, U6.20
ETH_TX_D2: U2.G19, U6.21
ETH_TX_D3: U2.F18, U6.22
ETH_TX_EN: U2.D19, U6.25
ETH_VDDA: C94.2, C95.2, C96.2, FB1.1, U6.1, U6.12
ETH_VDDL: C98.2, C99.2, C100.2, FB2.1, U6.4, U6.9
ETH_VDDL_PLL: C101.2, C102.2, C103.2, FB3.1, U6.44
FCS_B: R27.2, R28.2, U2.C23
GND: C1.1, C2.1, C3.1, C10.2, C17.2, C18.2, C19.2, C20.2, C21.2, C22.2, C23.2, C26.2, C27.2, C28.1, C29.2, C30.2, C32.2, C34.2, C37.1, C38.1, C39.1, C40.1, C41.1, C42.1, C43.1, C44.1, C45.1, C46.1, C47.1, C48.1, C49.1, C50.1, C51.1, C52.1, C53.1, C54.1, C55.1, C56.1, C57.1, C58.1, C59.1, C60.1, C61.1, C62.1, C63.2, C64.1, C65.1, C66.1, C67.1, C68.1, C69.1, C74.1, C75.1, C76.2, C77.2, C78.1, C79.2, C80.2, C81.2, C82.1, C83.1, C84.1, C85.1, C86.1, C87.1, C88.2, C89.1, C90.1, C91.1, C92.1, C93.1, C94.1, C95.1, C96.1, C97.1, C98.1, C99.1, C100.1, C101.1, C102.1, C103.1, C104.1, C105.1, C106.1, C107.1, C108.1, C109.1, C110.2, C111.2, C112.2, C113.2, C114.2, C115.2, C116.2, C117.1, C118.2, C119.2, C120.2, C121.2, C122.2, C123.2, C124.2, C125.2, C126.2, C127.2, C128.2, C129.2, C130.2, C131.2, C132.2, C133.2, C134.2, C135.2, C136.2, C137.2, C138.2, C139.2, C140.2, C141.2, C142.2, C143.2, C144.2, C145.2, C146.2, C147.2, C148.2, C149.2, C150.2, C151.2, C152.2, C153.2, C154.2, C155.2, C156.2, C157.2, C158.2, C159.2, C160.2, C161.2, C162.2, C163.2, C164.2, C165.2, C166.2, C167.2, C168.2, C169.2, C170.2, C171.2, C172.2, C173.2, C174.2, C175.2, C176.2, C177.2, C178.2, C179.2, C180.2, C181.2, C182.2, C183.2, C184.2, C185.2, C186.2, C187.2, C188.2, C189.1, C190.1, C191.2, C192.2, H1.1, H2.1, J1.1, J1.2, J1.12, J1.15, J1.18, J1.21, J1.24, J1.27, J1.30, J2.5, J3.1, R18.1, R24.1, R25.1, R34.2, R37.2, R40.2, R43.2, R46.2, R49.2, R51.1, R53.2, R55.2, R56.1, R60.1, R62.1, R72.1, R74.1, R78.2, R82.2, R83.2, R84.2, R85.2, R96.1, R97.2, R100.1, U1.7, U1.19, U1.31, U1.41, U1.44, U1.47, U1.50, U1.53, U1.56, U1.59, U1.62, U1.65, U1.68, U1.71, U1.74, U1.80, U1.94, U1.95, U1.98, U1.99, U1.110, U1.111, U1.116, U1.117, U1.123, U1.129, U1.161, U1.167, U1.173, U1.179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
HDMI_CEC: U1.197, U9.50
HDMI_CLK+: U1.165, U9.58
HDMI_CLK-: U1.163, U9.59
HDMI_D0+: U1.171, U9.62
HDMI_D0-: U1.169, U9.61
HDMI_D1+: U1.177, U9.65
HDMI_D1-: U1.175, U9.64
HDMI_D2+: U1.183, U9.68
HDMI_D2-: U1.181, U9.67
HDMI_HPD: R97.1, U1.199, U9.54
HDMI_RST_N: U2.C13, U9.51
HDMI_SCL: U1.195, U9.49
HDMI_SDA: U1.193, U9.48
MODE0: R79.2, R82.1, U2.T5
MODE1: R80.2, R83.1, U2.T2
MODE2: J3.2, U2.P5
unnamed: C4.2, U2.F2
unnamed: C5.2, U2.F1
unnamed: C6.2, U2.D2
unnamed: C7.2, U2.D1
unnamed: C11.1, C79.1, L1.2, R32.2, R33.1
unnamed: C11.2, R33.2, R34.1, U11.2
unnamed: C12.1, C63.1, L2.2, R35.2, R36.1
unnamed: C12.2, R36.2, R37.1, U12.2
unnamed: C13.1, C76.1, L3.2, R38.2, R39.1
unnamed: C13.2, R39.2, R40.1, U13.2
unnamed: C14.1, C80.1, L4.2, R41.2, R42.1
unnamed: C14.2, R42.2, R43.1, U14.2
unnamed: C15.1, C77.1, L5.2, R44.2, R45.1
unnamed: C15.2, R45.2, R46.1, U15.2
unnamed: C16.1, C81.1, L6.2, R47.2, R48.1
unnamed: C16.2, R48.2, R49.1, U16.2
unnamed: C22.1, R50.2, R51.2, U5.1
unnamed: C29.1, R54.2, U6.45, Y1.1
unnamed: C30.1, R54.1, U6.46, Y1.3
unnamed: C32.1, U7.M14
unnamed: C34.1, U7.A14
unnamed: C35.1, R65.1, U7.A12, Y2.3
unnamed: C36.1, R65.2, U7.A11, Y2.1
unnamed: C88.1, U17.2, Y3.1
unnamed: C191.1, U17.3, Y3.3
unnamed: D1.1, R24.2
unnamed: D1.2, R75.2, U2.G7
unnamed: D2.1, R25.2
unnamed: D2.2, R76.2, U2.J7
unnamed: J2.1, R19.2
unnamed: J2.2, R20.2
unnamed: J2.3, U2.R7
unnamed: J2.4, R21.2
unnamed: J3.3, R81.2
unnamed: L1.1, U11.6
unnamed: L2.1, U12.6
unnamed: L3.1, U13.6
unnamed: L4.1, U14.6
unnamed: L5.1, U15.6
unnamed: L6.1, U16.6
unnamed: R17.1, U2.U9
unnamed: R18.2, U2.T7
unnamed: R19.1, U2.N8
unnamed: R20.1, U2.R6
unnamed: R21.1, U2.L8
unnamed: R23.2, U2.P7
unnamed: R28.1, U10.1
unnamed: R29.1, U10.6
unnamed: R52.2, U8.A9
unnamed: R53.1, U8.J8
unnamed: R55.1, U6.48
unnamed: R56.2, U7.J12
unnamed: R57.2, U7.H12
unnamed: R58.1, R60.2, U7.N12
unnamed: R59.1, U7.L14
unnamed: R59.2, U7.L13
unnamed: R61.2, U7.M4
unnamed: R62.2, U7.L11
unnamed: R63.2, U7.K11
unnamed: R64.2, U7.M9
unnamed: R66.2, U7.M10
unnamed: R67.2, U7.M11
unnamed: R68.2, U7.M5
unnamed: R69.2, U7.C8
unnamed: R70.2, U7.D3
unnamed: R72.2, U7.L6
unnamed: R73.2, U7.C9
unnamed: R84.1, U3.L8
unnamed: R85.1, U4.L8
unnamed: R96.2, U9.56
unnamed: R98.1, U2.M6
unnamed: R99.1, U2.U4
unnamed: R100.2, U2.V12
unnamed: R101.2, U18.3
unnamed: TP8.1, U7.G11
unnamed: TP9.1, U7.D11
unnamed: TP10.1, U7.E11
unnamed: TP11.1, U7.E12
unnamed: TP12.1, U7.F11
PCIE1_CLK_HOST_N: C71.1, U17.7
PCIE1_CLK_HOST_P: C70.1, U17.6
PCIE1_CLK_N: U1.60, U17.9
PCIE1_CLK_P: U1.58, U17.8
PCIE1_RESETn: U1.37, U2.A17
PCIE1_RX_N: U1.54, U2.G3
PCIE1_RX_P: U1.52, U2.G4
PCIE1_TX_N: C5.1, U1.48
PCIE1_TX_P: C4.1, U1.46
PCIE2_CLK_N: C73.1, U1.66
PCIE2_CLK_P: C72.1, U1.64
PCIE2_RESETn: U1.24, U2.A18
PCIE2_RX_N: U1.78, U2.E3
PCIE2_RX_P: U1.76, U2.E4
PCIE2_TX_N: C7.1, U1.72
PCIE2_TX_P: C6.1, U1.70
PUDC_B: R77.2, R78.1, U2.B25
QSPI_DQ0: U2.B24, U10.5
QSPI_DQ1: U2.A25, U10.2
QSPI_DQ2: R30.2, U2.B22, U10.3
QSPI_DQ3: R31.2, U2.A22, U10.7
RAM_A0: R16.2, U2.AC8, U3.N3, U4.N3
RAM_A1: R8.2, U2.AA7, U3.P7, U4.P7
RAM_A2: R15.2, U2.AA8, U3.P3, U4.P3
RAM_A3: R7.2, U2.AF7, U3.N2, U4.N2
RAM_A4: R14.2, U2.AE7, U3.P8, U4.P8
RAM_A5: R6.2, U2.AC11, U3.P2, U4.P2
RAM_A6: R13.2, U2.V9, U3.R8, U4.R8
RAM_A7: R5.2, U2.Y10, U3.R2, U4.R2
RAM_A8: R12.2, U2.AB11, U3.T8, U4.T8
RAM_A9: R4.2, U2.Y7, U3.R3, U4.R3
RAM_A10: R11.2, U2.Y8, U3.L7, U4.L7
RAM_A11: R3.2, U2.V11, U3.R7, U4.R7
RAM_A12: R10.2, U2.V8, U3.N7, U4.N7
RAM_A13: R2.2, U2.W11, U3.T3, U4.T3
RAM_A14: R9.2, U2.Y11, U3.T7, U4.T7
RAM_A15: R1.2, U2.V7, U3.M7, U4.M7
RAM_BA0: R92.2, U2.AC7, U3.M2, U4.M2
RAM_BA1: R93.2, U2.AB7, U3.N8, U4.N8
RAM_BA2: R94.2, U2.AB9, U3.M3, U4.M3
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

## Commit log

2021-04-02 initial WIP commit
    [RAM.sch, TC358867XBG.step, TUSB1310ZAY.step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]
2021-04-08 some work on 6 power supplies, SPI flash
    [RAM.sch, reform-kintex.kicad_pcb, reform-kintex.sch]
2021-04-09 switch to TC358778XBG, some more connections here and there
    [RAM.sch]
2021-04-24 some more TUSB signals connected
    [RAM.sch]
2021-04-24 more TUSB noodling
    [RAM.sch]
2021-05-09 finish first draft of TUSB connectivity
    [RAM.sch]
2021-05-27 more DDR3 routing
    [RAM.sch, reform-kintex.kicad_pcb]
2021-05-28 ram bus termination
    [RAM.sch, reform-kintex.kicad_pcb]
2021-05-28 DSI and some USB routing
    [FH12-33S-0.5SH.stp, RAM.sch, reform-kintex.kicad_pcb]
2021-06-03 more routing, esp. ethernet
    [RAM.sch, reform-kintex.kicad_pcb]
2021-06-04 more routing, bunch of fpga bypass caps, logo
    [RAM.sch, reform-kintex.kicad_pcb]
2021-06-06 schematics: add many decoupling caps
    [RAM.sch, reform-kintex.kicad_pcb]
2021-06-09 ram bypass caps placed
    [RAM.sch, reform-kintex.kicad_pcb]
2021-06-16 place lots of caps; place some power supplies
    [RAM.sch, reform-kintex.kicad_pcb]
2021-06-17 place all components
    [RAM.sch, reform-kintex.kicad_pcb]
2021-06-20 more routing
    [RAM.sch, reform-kintex.kicad_pcb]
2021-07-05 more routing: 215 to go
    [RAM.sch, reform-kintex.kicad_pcb]
2021-07-06 add power sequencer, main clock, some missing resets, more routing (198)
    [RAM.sch, reform-kintex.kicad_pcb]
2021-07-07 more routing (39)
    [reform-kintex.kicad_pcb]
2021-07-07 fully routed
    [RAM.sch, reform-kintex.kicad_pcb, reform-kintex.sch]
2021-07-07 connect some missing i2c signals, backlight_en
    [RAM.sch, reform-kintex.kicad_pcb, reform-kintex.sch]
2021-07-07 silkscreen cleanup, 3d models, some footprint fixes
    [RAM.sch, reform-kintex.kicad_pcb, reform-kintex.sch]
2021-07-07 actual 3d models and footprints
    [ASFLMB.STEP, IHLP1212BZER3R3M11--3DModel-STEP-56544.STEP, LIFCL-40-7SG72C.stp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]
2021-07-09 DRC, polishing, bugfixes, badge
    [RAM.sch, reform-kintex.sch]
2021-07-09 add readme, schematics pdf, image
    [RAM.sch, reform-kintex.sch]
2021-07-10 pcb: fix some ram trace lengths
2021-07-11 WIP adjust ddr trace widths; prepare some TODOs for errors found with vivado
    [RAM.sch]
2021-07-11 reroute some DDR signals, tweak more track widths
    [RAM.sch]
2021-07-11 TUSB: fix VDDA1P8
    [RAM.sch]
2021-07-12 reroute all diff pairs
    [RAM.sch, reform-kintex.sch]
2021-07-12 add d-1 gerbers
2022-01-27 add some notes, gerbes and BOM after first D-1 bringup
    [RAM.sch, reform-kintex.csv, reform-kintex.sch]
2022-08-16 snapshot before touching RAM
    [RAM.kicad_sch, RAM.sch, reform-kintex.kicad_sch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]
2022-08-18 ddr new routing snapshot before length matching
    [RAM.kicad_sch]
2022-08-18 ddr new routing snapshot after length matching
    [RAM.kicad_sch]
2022-08-19 snapshot with tuned ddr address/command group
    [RAM.kicad_sch]
2022-08-19 snapshot after cleanup
    [RAM.kicad_sch, reform-kintex.kicad_sch]
2022-08-19 first finished layout of rev 2
    [RAM.kicad_sch, reform-kintex.kicad_sch]
2022-09-08 pcb: clean up D-2 BOM
    [FH12-50S-0.5SH.stp, RAM.kicad_sch, reform-kintex-d2-bom.ods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]
2022-10-03 schematic: minor cleanups
    [RAM.kicad_sch]
2022-10-03 BOM update
    [reform-kintex-d2-bom.ods, reform-kintex.csv]
2022-10-03 clean up schematics
    [RAM.kicad_sch, reform-kintex.kicad_sch]
2022-10-03 add ANX9807 footprint
2022-10-03 add RGB-eDP adapter kicad files
    [FH12-50S-0.5SH.stp, reform-kintex-edp.csv, reform-kintex-edp.kicad_pcb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]
2022-10-03 add eDP adapter schematics
